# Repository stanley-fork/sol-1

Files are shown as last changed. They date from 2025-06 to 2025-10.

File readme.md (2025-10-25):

# Sol-1 Homebrew Minicomputer

Sol-1 is a homebrew CPU and Minicomputer built from 74HC logic.
It is published here for educational purposes.

### Directory Struture
| Folder Name | Description |
| --- | --- |
| ccompiler | a c compiler written for the Sol-1 CPU. It outputs Sol-1 assembly |
| hardware | schematics, board pictures, microcode assembler |
| software | bios, kernel, shell, and unix utilities programs written in ASM for Sol-1 |
| solarium | the operating system for Sol-1 |
| systemverilog | systemverilog models for the Sol-1 CPU, computer, and a few other things |
| general_docs  | datasheets and miscellaneous documents related to Sol-1 and digital design in general | 
| sol1_docs | documents directly related to Sol-1 | 

## Features
### Hardware
- User and Kernel privilege modes, with up to 256 processes running in parallel.
- Paged virtual memory, such that each process can have a total of 64KB RAM for itself.
- Two serial ports (16550), a real time clock(M48T02), 2 parallel ports(8255), a programmable timer(8253), an IDE hard-drive interface(2.5 Inch HDD), a sound chip(AY-3-8910),
5.25" floppy drive controller (WD1770).
- 8 prioritized external interrupts
- DMA channel
- The sequencer is microcoded, with 15 ROMS operating horizontally
- 8/16-Bit MUL and DIV instructions
- Fast indexed string instructions in the spirit of x86's REP MOVSB, CMPSB, LODSB, STOSB, etc
- 32bit IEEE 754 Floating Point Unit (Under Development)
- 5.25" floppy drive :)

### Register Table
#### General Purpose Registers

| 16bit | 8bit  | Description |
| ----- | ----- | --- |
| A | AH/AL | Accumulator |
| B | BH/BL | Base Register (Secondary Counter Register) |
| C | CH/CL | Counter Register (Primary Counter) |
| D | DH/DL | Data Register / Data Pointer |
| G | GH/GL | General Register (For scratch) |

#### Special Purpose Registers

| 16bit  | 8bit | Description |
| --- | --- | --- |
| PC | | Program Counter |
| SP | | Stack Pointer |
| SSP | | Supervisor Stack Pointer |
| BP | | Base Pointer (Used to manage stack frames) |
| SI | | Source Index (Source address for string operations) |
| DI | | Destination Index (Destination address for string operations) |
| PTB | | Page Table Base |
| Status | | CPU Status |
| Flags  | | Arithmetic and Logic flags register |

### Software
- Unix-like operating system (in progress and very early)
- C compiler that generates a Sol-1 assembly output file
- SystemVerilog model

[Video demonstrations here](https://www.youtube.com/@PauloConstantino167/videos)

Wirewrap Board
Register Board
Front
Boot
Front

### Licensing Terms

Sol-1 Homebrew CPU/Minicomputer is a CPU + system around it, made from 74 series logic from scratch
as an educational project.
Copyright (C) 2025  Paulo Constantino

This program is free software; you can redistribute it and/or
modify it under the terms of the GNU General Public License
as published by the Free Software Foundation; either version 2
of the License, or (at your option) any later version.

This program is distributed in the hope that it will be useful,
but WITHOUT ANY WARRANTY; without even the implied warranty of
MERCHANTABILITY or FITNESS FOR A PARTICULAR PURPOSE.  See the
GNU General Public License for more details.

You should have received a copy of the GNU General Public License
along with this program; if not, see
<https://www.gnu.org/licenses/>.

contact: pconstantino@sol-1.org

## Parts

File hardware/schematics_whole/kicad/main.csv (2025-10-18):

# | Reference | Qty | Value | Footprint | DNP
1 | FLAGS0, IC32, IC33, IC60, IC75, IC76, IC77, IC78, IC79, IC134, IC135, IC136, IC231, IC259, IC266, IC267, IC334, IC336, IC338, INT_STATUS_REG0 | 20 | 74273N | main:DIL20
2 | IC1, IC13, IC15, IC39, IC49, IC55, IC63, IC90, IC98, IC100, IC104, IC112, IC114, IC118, IC121, IC122, IC125, IC127, IC142, IC147, IC195, IC206, IC341 | 23 | 74257N | main:DIL16
3 | IC2, IC3, IC5, IC6, IC9, IC12, IC14, IC16, IC20, IC23, IC30, IC41, IC42, IC44, IC53, IC56, IC61, IC62, IC67, IC68, IC69, IC71, IC80, IC81, IC82, IC84, IC85, IC86, IC87, IC88, IC89, IC130, IC133, IC141, IC144, IC152, IC160 | 37 | 74151N | main:DIL16
4 | IC4, IC17, IC26, IC27, IC65, IC72, IC97, IC120, IC150, IC161, IC163, IC185, IC207, IC209, IC211, IC218, IC219, IC222, IC223, IC224, IC225, IC228, IC229, IC230 | 24 | 74244N | main:DIL20
5 | IC7, IC24, IC54, IC96, IC128, IC129, IC131, IC132 | 8 | 74157N | main:DIL16
6 | IC8, IC19, IC28, IC31, IC48, IC57, IC66, IC99, IC101, IC102, IC106, IC109, IC110, IC117, IC123, IC157, IC158, IC159, IC162, IC165, IC166, IC169, IC171, IC172, IC177, IC178, IC183, IC184, IC198, IC204, IC210, IC245, IC260, INT_CODE_REG1 | 34 | 74377N | main:DIL20
7 | IC10, IC11 | 2 | 74181N | main:DIL24-6
8 | IC18, IC94, IC151, IC153, IC167, IC174, IC263 | 7 | 7432N | main:DIL14
9 | IC21, IC140 | 2 | 58C256P | main:DIL28-6
10 | IC22, IC45, IC93, IC119, IC143, IC146, IC201, IC236 | 8 | 7408N | main:DIL14
11 | IC25, IC173, IC202 | 3 | 7427N | main:DIL14
12 | IC29, IC34, IC35, IC36, IC37, IC38, IC40, IC47, IC64, IC73, IC83, IC92, IC103, IC116, IC124, IC180, IC237, IC241, IC255, IC270 | 20 | 74153N | main:DIL16
13 | IC43, IC115, IC138, IC154, IC155, IC156, IC176, IC196, IC197, IC205, IC_04_2 | 11 | 7404N | main:DIL14
14 | IC46, IC50, IC51, IC52 | 4 | 74283N | main:DIL16
15 | IC58 | 1 | 7411N | main:DIL14
16 | IC59, IC175, IC_86_0, IC_86_1 | 4 | 7486N | main:DIL14
17 | IC74, IC107, IC108, IC126, IC137, IC190 | 6 | 7474N | main:DIL14
18 | IC91, IC95, IC111, IC113, IC170, IC179, IC181, IC182 | 8 | 74253N | main:DIL16
19 | IC105 | 1 | 74148N | main:DIL16
20 | IC139, IC148 | 2 | 7400N | main:DIL14
21 | IC145, IC_10_0 | 2 | 7410N | main:DIL14
22 | IC149, IC164, IC254 | 3 | 74138N | main:DIL16
23 | IC168 | 1 | 7420N | main:DIL14
24 | IC186 | 1 | 4040N | main:DIL16
25 | IC187 | 1 | 431000 | main:DIL32
26 | IC188, IC199, IC227, IC243, IC257, IC258, IC261, IC262, IC264, IC265, IC302, IC303, IC333, IC335, IC337, IC339 | 16 | 27512 | main:DIL28
27 | IC192, IC193, IC194, IC411 | 4 | 74279N | main:DIL16
28 | IC203 | 1 | 7430N | main:DIL14
29 | IC208 | 1 | 74245N | main:DIL20
30 | IC412 | 1 | 74173N | main:DIL16
31 | IC_02_0 | 1 | 7402N | main:DIL14
32 | R1, R2, R3, R4, R5, R6, R7, R8, R9, R10, R11, R12, R13, R14, R15, R16, R17, R18, R19, R20, R21, R22, R23, R24, R25, R26, R27, R28 | 28 | R-US_0204/2V | main:0204V
33 | S5, S7, S8 | 3 | tl36po | main:TL3XPO
34 | SW1, SW2, SW3, SW4, SW5 | 5 | SW_DIP-8 | main:EDG-08
35 | U1, U2, U3, U4, U5, U6, U7, U8 | 8 | as6c4008-55pcn | main:DIP254P1524X393-32

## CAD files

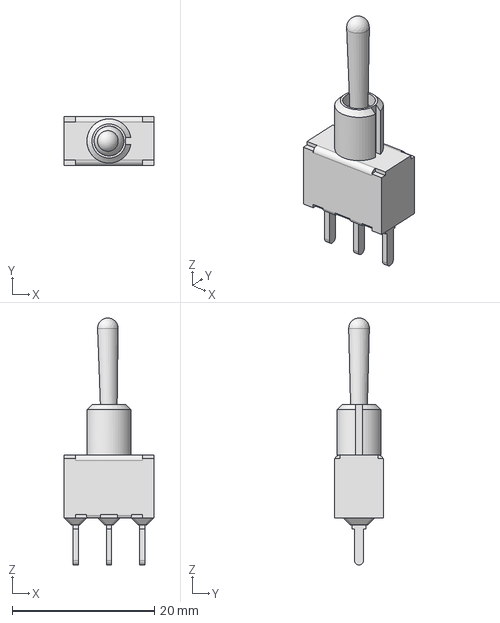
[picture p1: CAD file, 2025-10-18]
hardware/schematics_whole/kicad_models/100SP1T1B4M2QE.step
12.7 x 6.86 x 34.8 mm

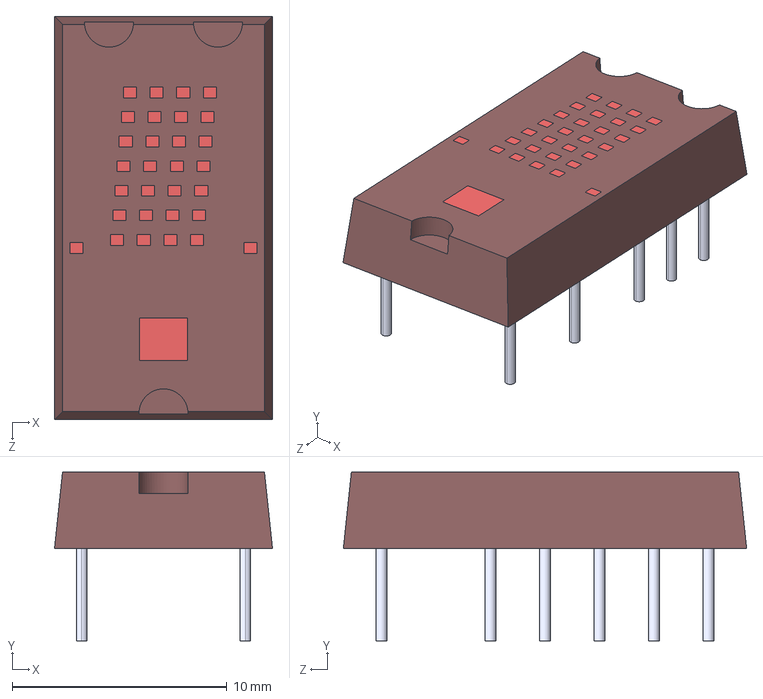
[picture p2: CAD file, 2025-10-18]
hardware/schematics_whole/kicad_models/KiCad-libs-master/TIL311--3DModel-STEP-56544.STEP
10.2 x 7.87 x 18.8 mm

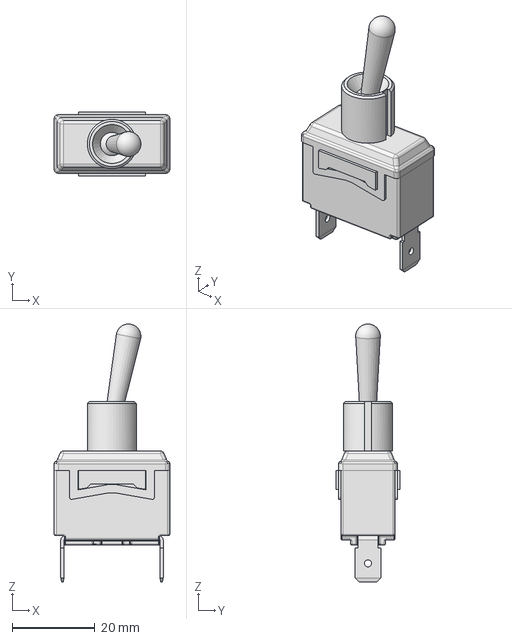
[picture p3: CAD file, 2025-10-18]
hardware/schematics_whole/kicad_models/ST141D00.step
28.0 x 15.5 x 62.4 mm

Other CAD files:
hardware/photon/main.obj
hardware/photon/photon.obj

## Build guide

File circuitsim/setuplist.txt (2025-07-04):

### setuplist.txt first line must be a comment
+Basics
ohms.txt Ohm's Law
resistors.txt Resistors
cap.txt Capacitor
induct.txt Inductor
>lrc.txt LRC Circuit
voltdivide.txt Voltage Divider
pot.txt Potentiometer
potdivide.txt Potentiometer Divider
thevenin.txt Thevenin's Theorem
norton.txt Norton's Theorem
-
+A/C Circuits
capac.txt Capacitor
inductac.txt Inductor
capmultcaps.txt Caps of Various Capacitances
capmultfreq.txt Caps w/ Various Frequencies
indmultind.txt Inductors of Various Inductances
indmultfreq.txt Inductors w/ Various Frequencies
impedance.txt Impedances of Same Magnitude
res-series.txt Series Resonance
res-par.txt Parallel Resonance
-
+Passive Filters
filt-hipass.txt High-Pass Filter (RC)
filt-lopass.txt Low-Pass Filter (RC)
filt-hipass-l.txt High-Pass Filter (RL)
filt-lopass-l.txt Low-Pass Filter (RL)
bandpass.txt Band-pass Filter
notch.txt Notch Filter
twint.txt Twin-T Filter
crossover.txt Crossover
butter10lo.txt Butterworth Low-Pass (10 pole)
besselbutter.txt Bessel vs Butterworth
ringing.txt Band-pass with Ringing
-
+Other Passive Circuits
+Series/Parallel
indseries.txt Inductors in Series
indpar.txt Inductors in Parallel
capseries.txt Caps in Series
cappar.txt Caps in Parallel
-
+Transformers
transformer.txt Transformer
transformerdc.txt Transformer w/ DC
transformerup.txt Step-Up Transformer
transformerdown.txt Step-Down Transformer
longdist.txt Long-Distance Power Transmission
-
+Relays
relay.txt Relay
relayand.txt Relay AND
relayor.txt Relay OR
relayxor.txt Relay XOR
relaymux.txt Relay Mux
relayff.txt Relay Flip-Flop
relaytff.txt Relay Toggle Flip-Flop
relayctr.txt Relay Counter
-
3way.txt 3-Way Light Switches
4way.txt 3- and 4-Way Light Switches
diff.txt Differentiator
wheatstone.txt Wheatstone Bridge
lrc-critical.txt Critically Damped LRC
currentsrcelm.txt Current Source
inductkick.txt Inductive Kickback
inductkick-snub.txt Blocking Inductive Kickback
powerfactor1.txt Power Factor
powerfactor2.txt Power Factor Correction
grid.txt Resistor Grid
grid2.txt Resistor Grid 2
cube.txt Resistor Cube
+Coupled LC's
coupled1.txt LC Modes (2)
coupled2.txt Weak Coupling
coupled3.txt LC Modes (3)
ladder.txt LC Ladder
-
phaseseq.txt Phase-Sequence Network
lissa.txt Lissajous Figures
-
+Diodes
diodevar.txt Diode
diodecurve.txt Diode I/V Curve
rectify.txt Half-Wave Rectifier
fullrect.txt Full-Wave Rectifier
fullrectf.txt Full-Wave Rectifier w/ Filter
diodelimit.txt Diode Limiter
+Zener Diodes
zeneriv.txt I/V Curve
zenerref.txt Voltage Reference
zenerreffollow.txt Voltage Reference w/ Follower
-
dcrestoration.txt DC Restoration
inductkick-block.txt Blocking Inductive Kickback
spikegen.txt Spike Generator
+Voltage Multipliers
voltdouble.txt Voltage Doubler
voltdouble2.txt Voltage Doubler 2
volttriple.txt Voltage Tripler
voltquad.txt Voltage Quadrupler
-
amdetect.txt AM Detector
diodeclip.txt Waveform Clipper
sinediode.txt Triangle-to-Sine Converter
ringmod.txt Ring Modulator
-
+Op-Amps
opamp.txt Op-Amp
opampfeedback.txt Op-Amp Feedback
+Amplifiers
amp-invert.txt Inverting Amplifier
amp-noninvert.txt Noninverting Amplifier
amp-follower.txt Follower
amp-diff.txt Differential Amplifier
amp-sum.txt Summing Amplifier
logconvert.txt Log Amplifier
classd.txt Class-D Amplifier
-
+Oscillators
relaxosc.txt Relaxation Oscillator
phaseshiftosc.txt Phase-Shift Oscillator
triangle.txt Triangle Wave Generator
sine.txt Sine Wave Generator
sawtooth.txt Sawtooth Wave Generator
vco.txt Voltage-Controlled Oscillator
rossler.txt Rossler Circuit
-
amp-rect.txt Half-Wave Rectifier (inverting)
amp-fullrect.txt Full-Wave Rectifier
peak-detect.txt Peak Detector
amp-integ.txt Integrator
amp-dfdx.txt Differentiator
amp-schmitt.txt Schmitt Trigger
nic-r.txt Negative Impedance Converter
gyrator.txt Gyrator
capmult.txt Capacitance Multiplier
howland.txt Howland Current Source
itov.txt I-to-V Converter
opamp-regulator.txt Voltage Regulator
opint.txt 741 Internals
opint-invert-amp.txt 741 (inverting amplifier)
opint-slew.txt 741 Slew Rate
opint-current.txt 741 Current Limits
-
+Transistors
npn.txt NPN Transistor
pnp.txt PNP Transistor
transswitch.txt Switch
follower.txt Emitter Follower
+Multivibrators
multivib-a.txt Astable Multivib
multivib-bi.txt Bistable Multivib (Flip-Flop)
multivib-mono.txt Monostable Multivib (One-Shot)
-
ceamp.txt Common-Emitter Amplifier
phasesplit.txt Unity-Gain Phase Splitter
schmitt.txt Schmitt Trigger
currentsrc.txt Current Source
currentsrcramp.txt Current Source Ramp
mirror.txt Current Mirror
darlington.txt Darlington Pair
+Differential Amplifiers
trans-diffamp.txt Differential Input
trans-diffamp-common.txt Common-Mode Input
trans-diffamp-cursrc.txt Common-Mode w/Current Source
-
+Push-Pull Follower
pushpullxover.txt Simple, with distortion
pushpull.txt Improved
-
+Oscillators
colpitts.txt Colpitts Oscillator
hartley.txt Hartley Oscillator
eclosc.txt Emitter-Coupled LC Oscillator
-
-
+MOSFETs
nmosfet.txt n-MOSFET
pmosfet.txt p-MOSFET
mosswitch.txt Switch
mosfollower.txt Source Follower
moscurrentsrc.txt Current Source
moscurrentramp.txt Current Ramp
mosmirror.txt Current Mirror
mosfetamp.txt Common-Source Amplifier
cmosinverter.txt CMOS Inverter
cmosinvertercap.txt CMOS Inverter (w/capacitance)
cmosinverterslow.txt CMOS Inverter (slow transition)
cmostransgate.txt CMOS Transmission Gate
mux.txt CMOS Multiplexer
samplenhold.txt Sample-and-Hold
delayrc.txt Delayed Buffer
leadingedge.txt Leading-Edge Detector
switchfilter.txt Switchable Filter
voltinvert.txt Voltage Inverter
invertamp.txt Inverter Amplifier
inv-osc.txt Inverter Oscillator
-
+555 Timer Chip
555square.txt Square Wave Generator
555int.txt Internals
555saw.txt Sawtooth Oscillator
555lowduty.txt Low-duty-cycle Oscillator
555monostable.txt Monostable Multivibrator
555pulsemod.txt Pulse Width Modulator
555sequencer.txt Pulse Sequencer
555schmitt.txt Schmitt Trigger (inverting)
555missing.txt Missing Pulse Detector
-
+Active Filters
filt-vcvs-lopass.txt VCVS Low-Pass Filter
filt-vcvs-hipass.txt VCVS High-Pass Filter
switchedcap.txt Switched-Capacitor Filter
allpass1.txt Allpass
allpass2.txt Allpass w/ Square
-
+Logic Families
+RTL
rtlinverter.txt RTL Inverter
rtlnor.txt RTL NOR
rtlnand.txt RTL NAND
-
+DTL
dtlinverter.txt DTL Inverter
dtlnand.txt DTL NAND
dtlnor.txt DTL NOR
-
+TTL
ttlinverter.txt TTL Inverter
ttlnand.txt TTL NAND
ttlnor.txt TTL NOR
-
+NMOS
nmosinverter.txt NMOS Inverter
nmosinverter2.txt NMOS Inverter 2
nmosnand.txt NMOS NAND
-
+CMOS
cmosinverter.txt CMOS Inverter
cmosnand.txt CMOS NAND
cmosnor.txt CMOS NOR
cmosxor.txt CMOS XOR
cmosff.txt CMOS Flip-Flop
cmosmsff.txt CMOS Master-Slave Flip-Flop
-
+ECL
eclnor.txt ECL NOR/OR
-
+Ternary
3-cgand.txt CGAND
3-cgor.txt CGOR
3-invert.txt Complement (F210)
3-f211.txt F211
3-f220.txt F220
3-f221.txt F221
-
-
+Combinational Logic
xor.txt Exclusive OR
halfadd.txt Half Adder
fulladd.txt Full Adder
decoder.txt 1-of-4 Decoder
mux3state.txt 2-to-1 Mux
majority.txt Majority Logic
digcompare.txt 2-Bit Comparator
7segdecoder.txt 7-Segment LED Decoder
-
+Sequential Logic
+Flip-Flops
nandff.txt SR Flip-Flop
clockedsrff.txt Clocked SR Flip-Flop
masterslaveff.txt Master-Slave Flip-Flop
edgedff.txt Edge-Triggered D Flip-Flop
jkff.txt JK Flip-Flop
-
+Counters
counter.txt 4-Bit Ripple Counter
counter8.txt 8-Bit Ripple Counter
synccounter.txt Synchronous Counter
deccounter.txt Decimal Counter
graycode.txt Gray Code Counter
johnsonctr.txt Johnson Counter
-
divideby2.txt Divide-by-2
divideby3.txt Divide-by-3
ledflasher.txt LED Flasher
traffic.txt Traffic Light
dram.txt Dynamic RAM
-
+Analog/Digital
flashadc.txt Flash ADC
deltasigma.txt Delta-Sigma ADC
hfadc.txt Half-Flash (Subranging) ADC
dac.txt Binary-Weighted DAC
r2rladder.txt R-2R Ladder DAC
swtreedac.txt Switch-Tree DAC
digsine.txt Digital Sine Wave
-
+Phase-Locked Loops
xorphasedet.txt XOR Phase Detector
pll.txt Type I PLL
phasecomp.txt Phase Comparator (Type II)
phasecompint.txt Phase Comparator Internals
pll2.txt Type II PLL
pll2a.txt Type II PLL (fast)
freqdouble.txt Frequency Doubler
-
+Transmission Lines
tl.txt Simple TL
tlstand.txt Standing Wave
tlterm.txt Termination
tlmismatch.txt Mismatched lines (Pulse)
tlmis1.txt Mismatched lines (Standing Wave)
tlmatch1.txt Impedance Matching (L-Section)
tlmatch2.txt Impedance Matching (Shunt Stub)
tlfreq.txt Stub Frequency Response
tllopass.txt Low-Pass Filter
tllight.txt Light Switch
-
+Misc Devices
+JFETs
jfetcurrentsrc.txt JFET Current Source
jfetfollower.txt JFET Follower
jfetfollower-nooff.txt JFET Follower w/zero offset
jfetamp.txt Common-Source Amplifier
volume.txt Volume Control
-
+Tunnel Diodes
tdiode.txt I/V Curve
tdosc.txt LC Oscillator
tdrelax.txt Relaxation Oscillator
-
+Memristors
mr.txt Memristor
mr-sine.txt Sine Wave
mr-square.txt Square Wave
mr-triangle.txt Triangle Wave
mr-sine2.txt Hard-Switching 1
mr-sine3.txt Hard-Switching 2
mr-crossbar.txt Crossbar Memory
-
+Triodes
triode.txt Triode
triodeamp.txt Amplifier
-
+Silicon-Controlled Rectifiers
scr.txt SCR
scractrig.txt AC Trigger
-
+Current Conveyor
cc2.txt CCII+
cc2n.txt CCII-
ccinductor.txt Inductor Simulator
cc2imp.txt CCII+ Implementation
cc2impn.txt CCII- Implementation
cciamp.txt Current Amplifier
ccvccs.txt VCCS
ccdiff.txt Current Differentiator
ccint.txt Current Integrator
ccitov.txt Current-Controlled Voltage Source
-
+Spark Gap
spark-sawtooth.txt Sawtooth Generator
tesla.txt Tesla Coil
spark-marx.txt Marx Generator
-
-
blank.txt Blank Circuit

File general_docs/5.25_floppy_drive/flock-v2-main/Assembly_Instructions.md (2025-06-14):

# Flock Version 2.0 - Assembly Instructions

## Prerequisites

### Tools, Equipment, and Supplies

* Soldering iron with a fine tip. Temperature controlled soldering station is recommended
* Needle nose pliers for forming components' leads
* Small side cutters for cutting components' leads
* Multimeter with frequency measurement, an oscilloscope, or a logic analyzer can be beneficial for troubleshooting
* Desk lamp, magnifying glass
* Solder suitable for soldering electronics. For example: rosin core Sn63/Pb37, Sn60/Pb40, or a lead-free solder such as Sn96.5/Ag3.0/Cu0.5 (sometimes referred to as SAC305)
* Solder wick for removing excess of solder
* 99% Isopropyl Alcohol for removing the excess of flux after soldering
* Lint free wipes, used toothbrush, cotton swabs for cleaning the PCB before and after soldering

### Parts

The table below shows the images of the components included in the kit. The up to date list of parts provided in the [Bill of Materials](README.md#bill-of-materials) section of the [README.md](README.md) file. It also provides the recommended sources for the parts.

Image                                                                                           | Reference | Description                                            | Quantity
----------------------------------------------------------------------------------------------- | --------- | ------------------------------------------------------ | --------
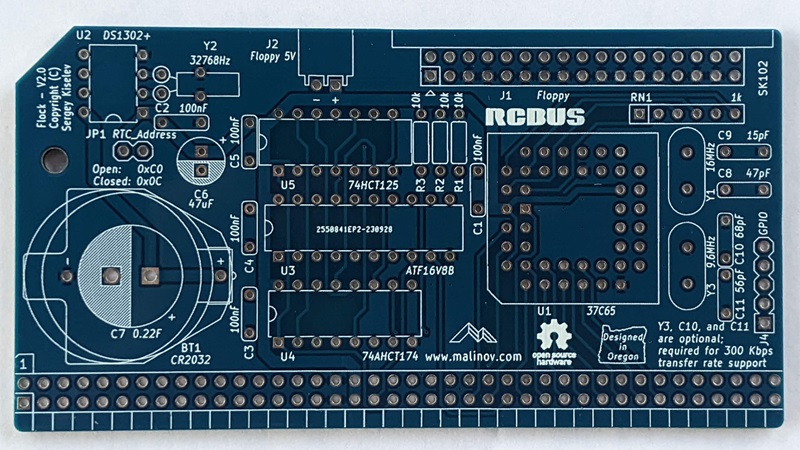
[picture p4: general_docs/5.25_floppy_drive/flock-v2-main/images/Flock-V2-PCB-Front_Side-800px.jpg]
PCB - Flock V2
             | PCB       | Flock PCB - Version 2.0                                | 1
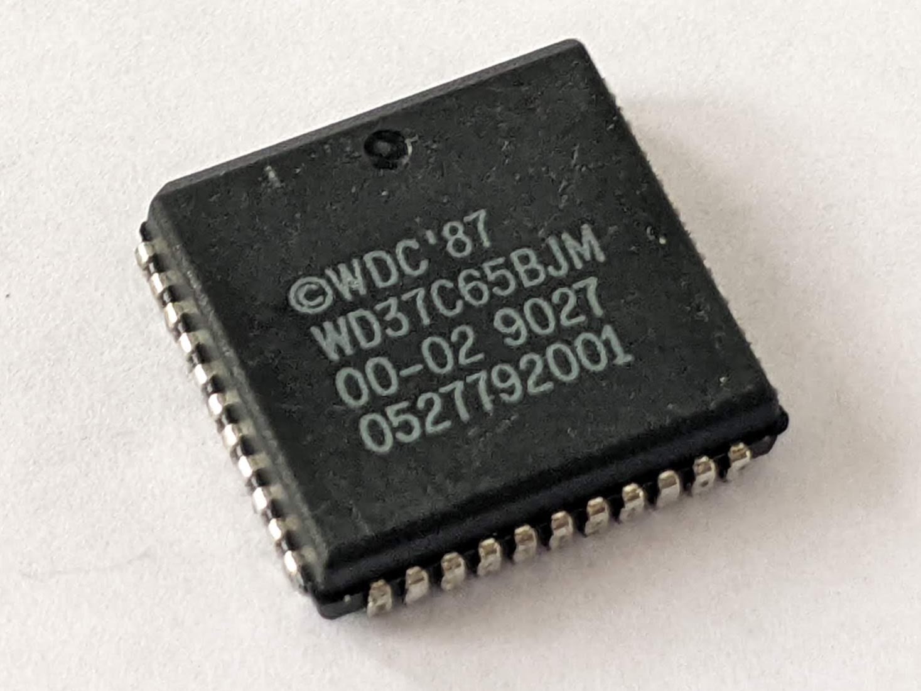
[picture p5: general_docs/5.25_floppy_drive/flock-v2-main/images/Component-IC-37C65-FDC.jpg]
FDC - 37C65
                    | U1        | WD37C65BJM - FDC, CMOS, 44 pin PLCC                    | 1
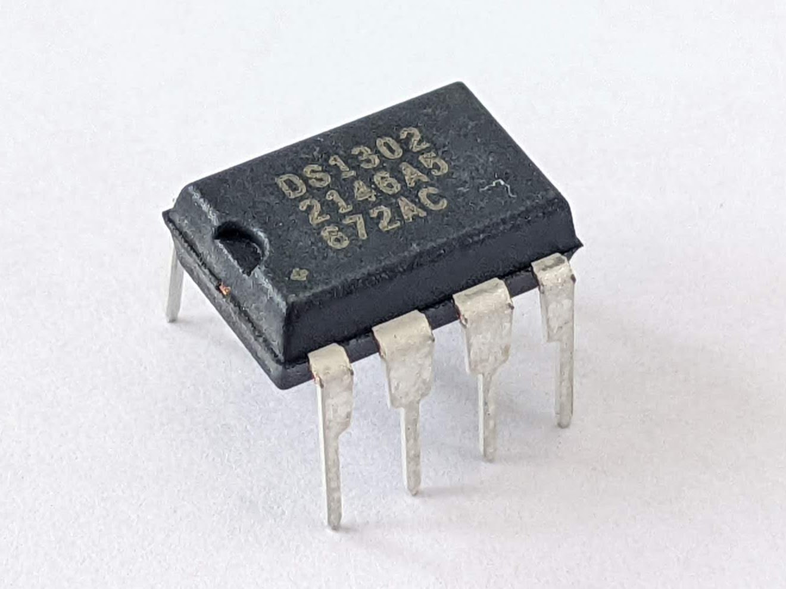
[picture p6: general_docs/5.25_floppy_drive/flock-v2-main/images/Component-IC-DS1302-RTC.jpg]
RTC - DS1302+
                 | U2        | DS1302+ - RTC, 8 pin DIP                               | 1
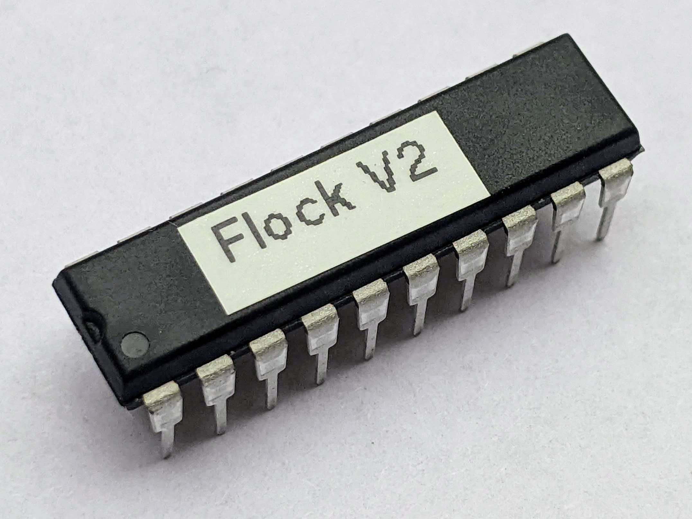
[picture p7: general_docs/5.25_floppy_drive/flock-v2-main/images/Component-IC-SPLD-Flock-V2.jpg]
Flock V2 SPLD - ATF16V8B
   | U3        | ATF16V8B SPLD, programmed with Flock V2 fuse map, 20 pin DIP | 1
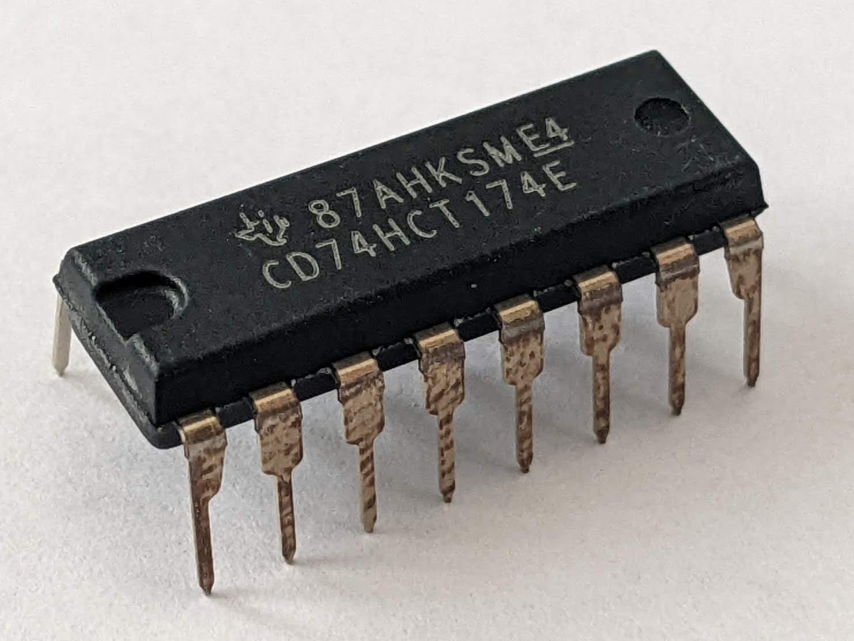
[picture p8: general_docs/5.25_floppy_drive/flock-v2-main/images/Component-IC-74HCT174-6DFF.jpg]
Hex D Flip-Flop - 74HCT174
 | U4        | 74HCT174 - Hex D-type flip-flop with reset, 16 pin DIP | 1
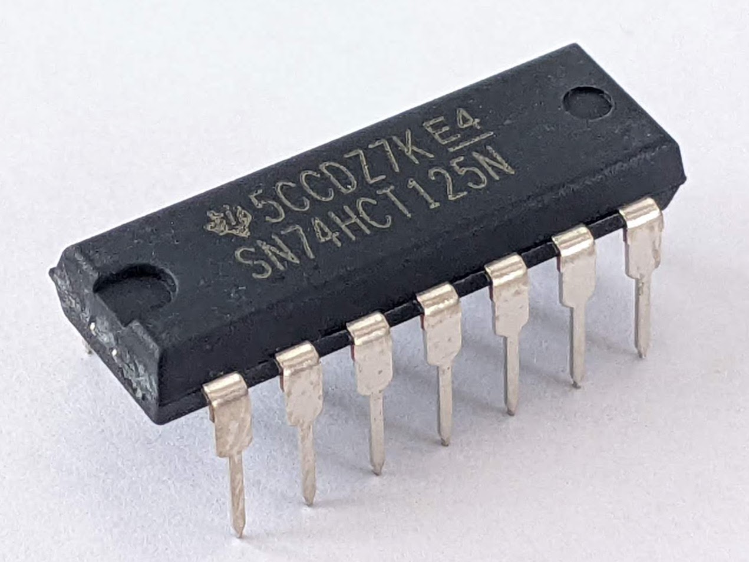
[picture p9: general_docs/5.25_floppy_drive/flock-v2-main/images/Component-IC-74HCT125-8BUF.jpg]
3-State Buffer - 74HCT125
  | U5        | 74HCT125 - Quadruple bus buffer gates with 3-state outputs, 14 pin DIP | 1 
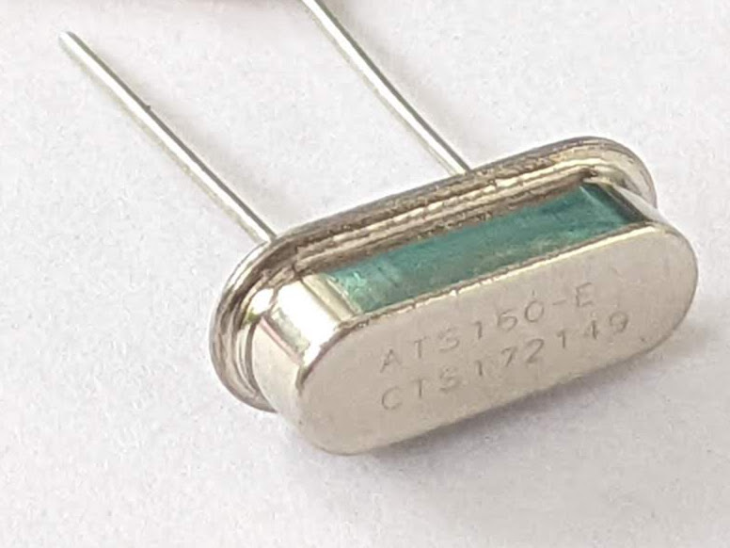
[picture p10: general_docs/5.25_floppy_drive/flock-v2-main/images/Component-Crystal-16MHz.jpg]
16 MHz Quartz Crystal
         | Y1        | Quarts crystal, 16 MHz, series                         | 1
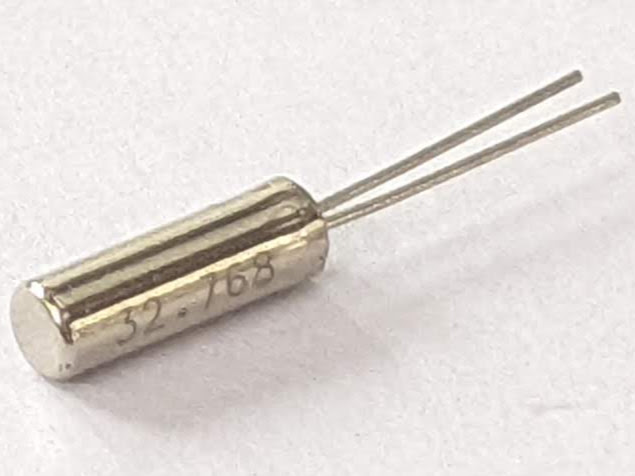
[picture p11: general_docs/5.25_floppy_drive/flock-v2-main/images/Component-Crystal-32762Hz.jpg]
32762 Hz Quartz Crystal
     | Y2        | Quarts crystal, 32768 Hz, 6 pF                         | 1
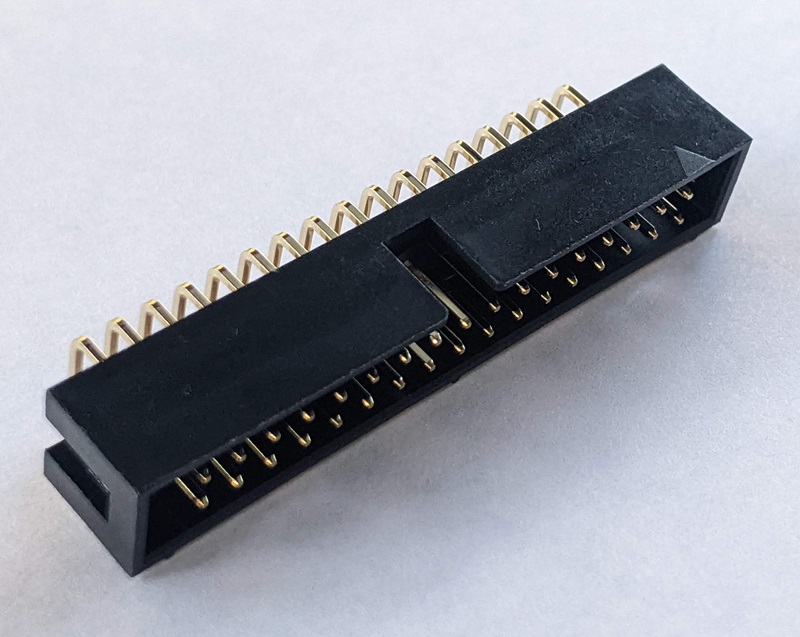
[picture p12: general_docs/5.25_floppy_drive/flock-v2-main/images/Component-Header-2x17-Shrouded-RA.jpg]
2x17 Shrouded Pin Header Right Angle
 | J1      | Pin header, shrouded, 2x17 pins, right angle, 2.54 mm pitch | 1
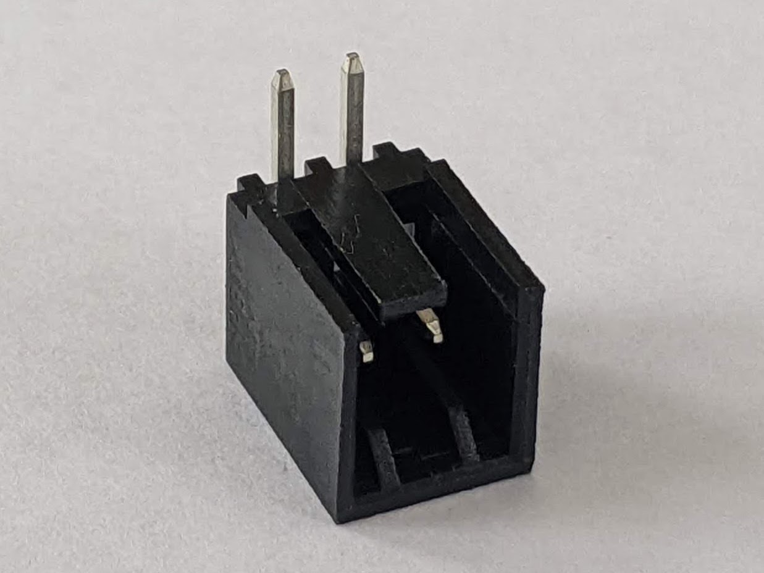
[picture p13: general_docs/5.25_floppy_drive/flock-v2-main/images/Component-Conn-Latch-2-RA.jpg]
Friction Lock Connector
     | J2        | Pin header with friction lock, 2 pins, right angle     | 1 (optional)
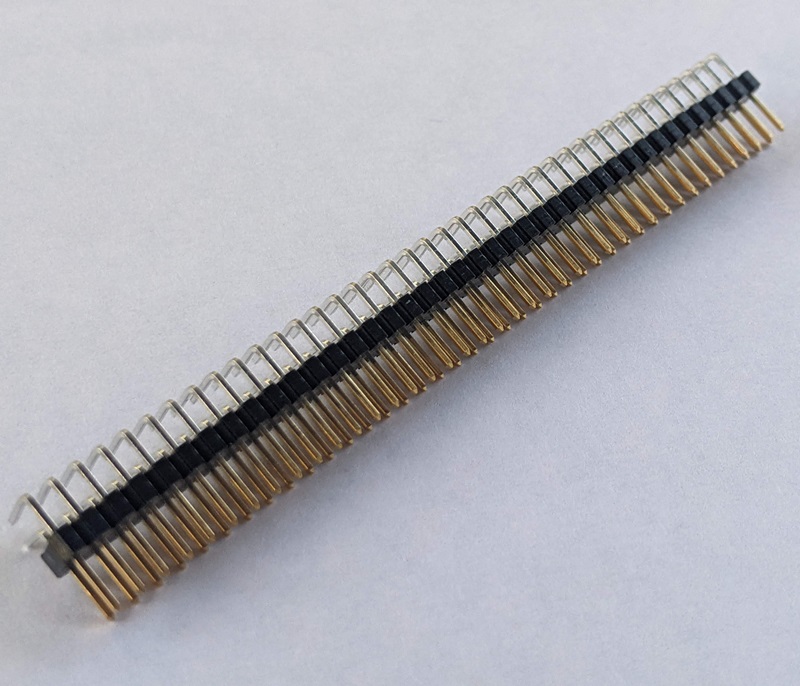
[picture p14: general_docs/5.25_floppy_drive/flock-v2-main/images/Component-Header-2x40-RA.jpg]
Pin Header 2x40 Right Angle
  | J3        | Pin header, 2x40 pins, 2.54 mm pitch, right angle      | 1
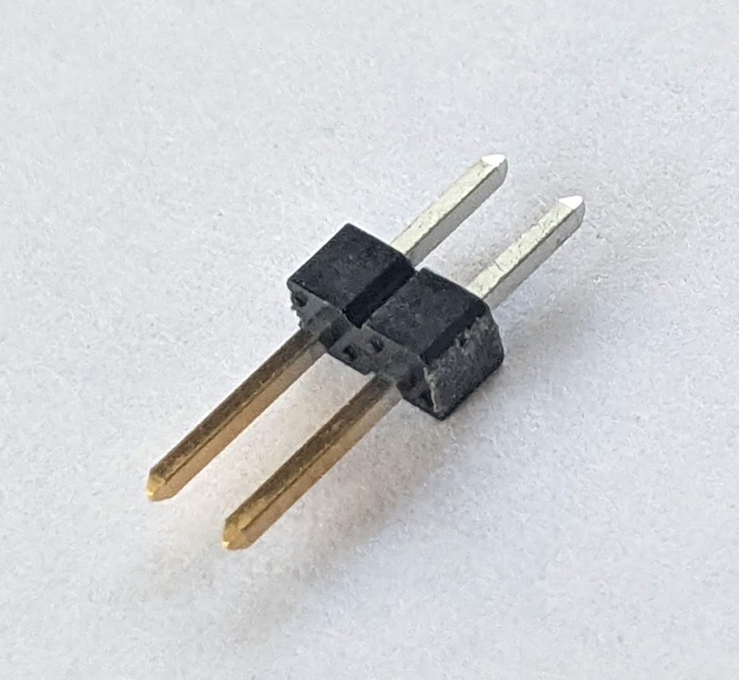
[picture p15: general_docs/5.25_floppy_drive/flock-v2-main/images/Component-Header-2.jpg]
Pin Header 2 pins
                  | JP1       | Pin header, 2 pins, 2.54 mm pitch                      | 1
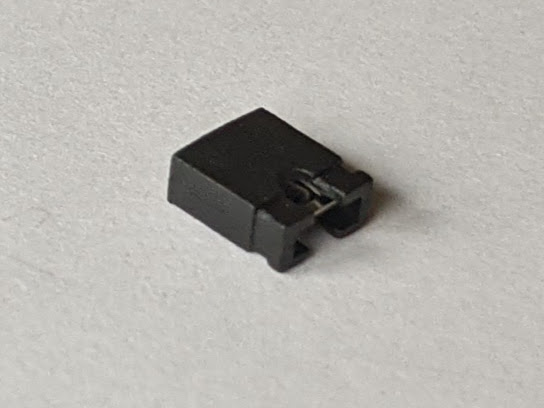
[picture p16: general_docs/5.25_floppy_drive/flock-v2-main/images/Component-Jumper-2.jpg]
Jumper
                             | JP1       | Jumper/Shunt, 2 pin 2.54 mm pitch
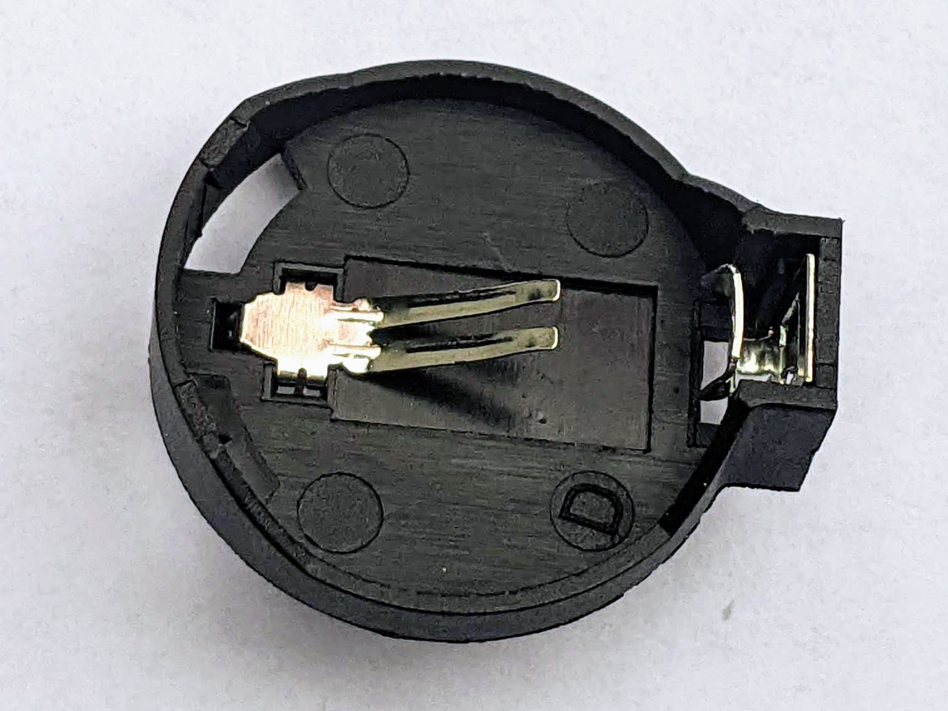
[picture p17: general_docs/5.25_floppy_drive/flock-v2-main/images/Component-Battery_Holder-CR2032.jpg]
CR2032 Battery Holder
 | BT1       | Battery Holder, CR2032 (optional; C7 can be installed instead) | 1
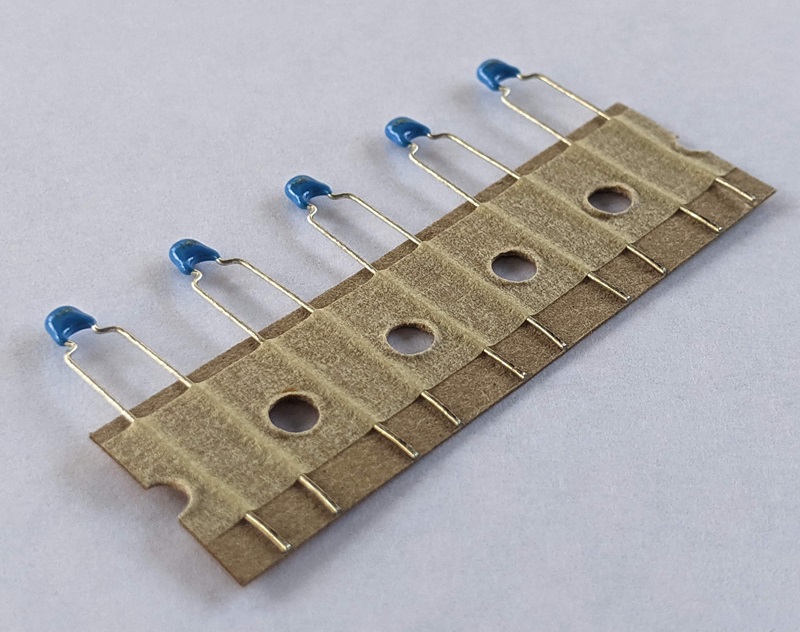
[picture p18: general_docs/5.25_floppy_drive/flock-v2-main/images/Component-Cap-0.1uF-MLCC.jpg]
Ceramic Capacitors - 0.1uF
   | C1 - C5   | Capacitor, MLCC, 0.1 uF, 50V, 5 mm pitch               | 5
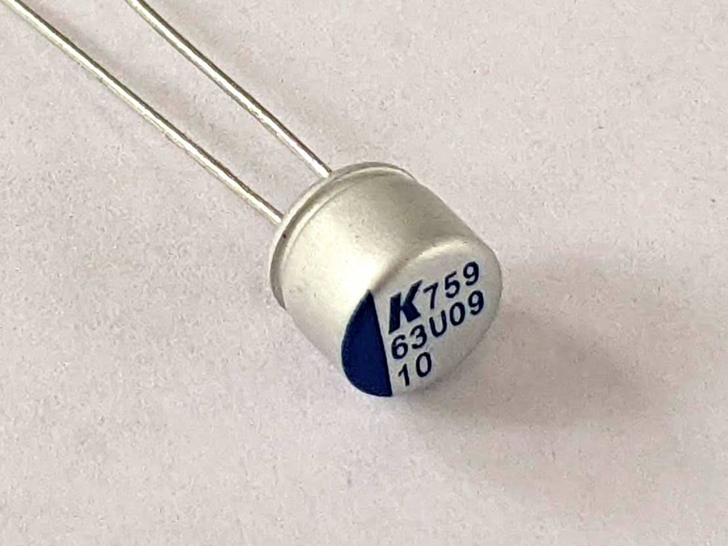
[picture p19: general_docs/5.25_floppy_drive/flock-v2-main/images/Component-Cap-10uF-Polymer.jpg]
Organic Polymer Capacitor - 10uF
 | C6  | Capacitor, Organic Polymer, 10 uF, 63V, 6.3 mm diameter, 2.5 mm pitch (optional; BT1 can be installed instead) | 1
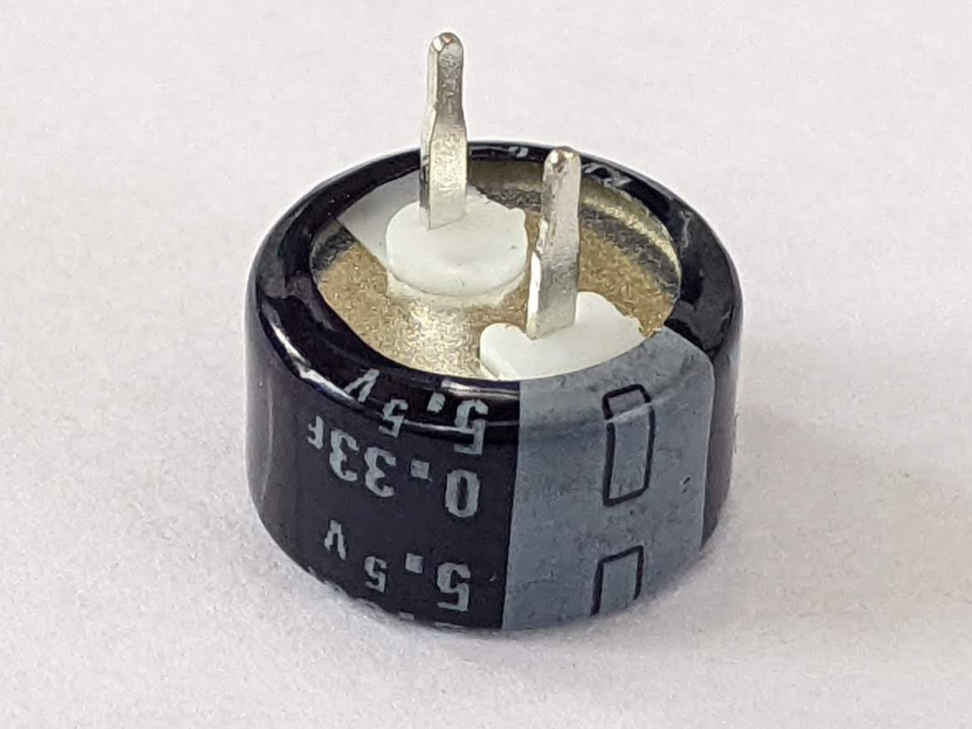
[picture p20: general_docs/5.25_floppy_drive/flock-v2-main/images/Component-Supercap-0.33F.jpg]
Supercapacitor - 0.33F
       | C7        | Supercapacitor, 0.22 F, 5.5V, 13.5 mm diameter, 5 mm pitch            | 1
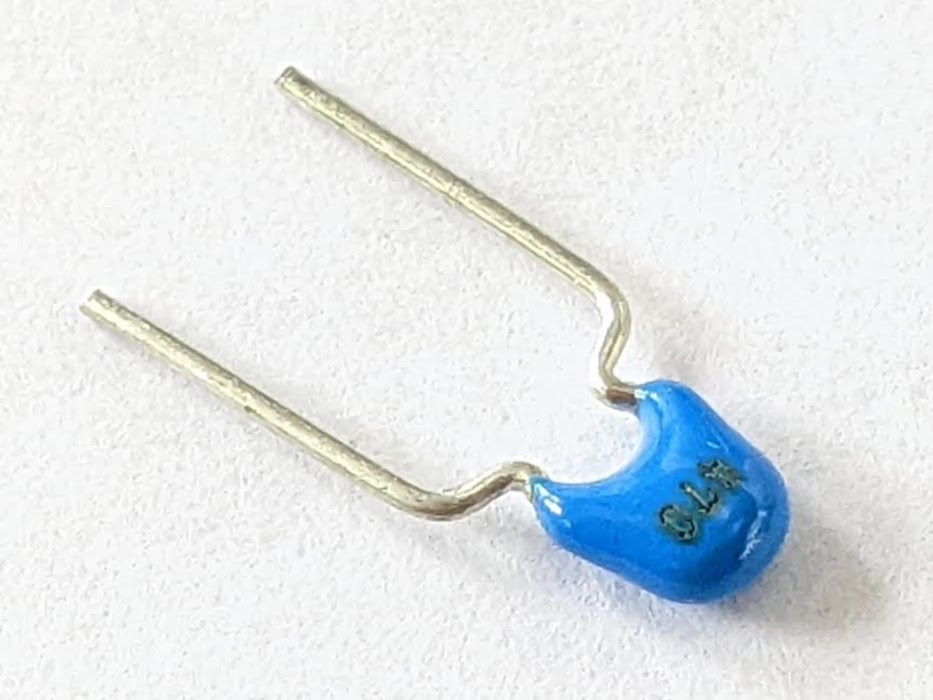
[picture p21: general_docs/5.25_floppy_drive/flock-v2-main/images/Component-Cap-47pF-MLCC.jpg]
Ceramic Capacitor - 47pF
      | C8        | Capacitor, MLCC, 47 pF, 50V, 5 mm pitch                | 1
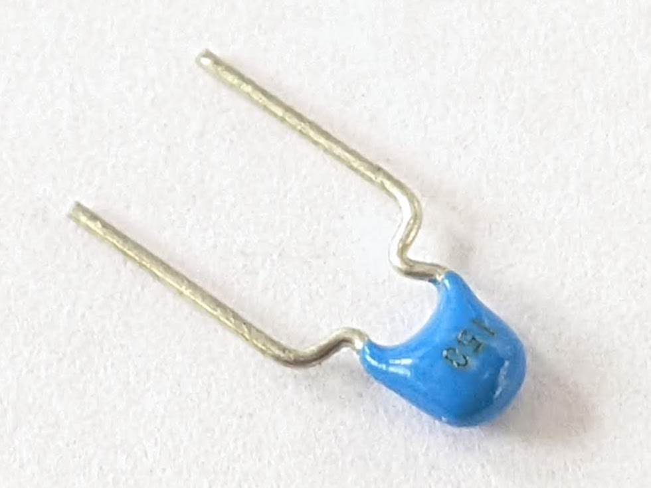
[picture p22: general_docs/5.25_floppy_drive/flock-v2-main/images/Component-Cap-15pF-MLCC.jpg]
Ceramic Capacitor - 15pF
      | C9        | Capacitor, MLCC, 15 pF, 50V, 5 mm pitch                | 1
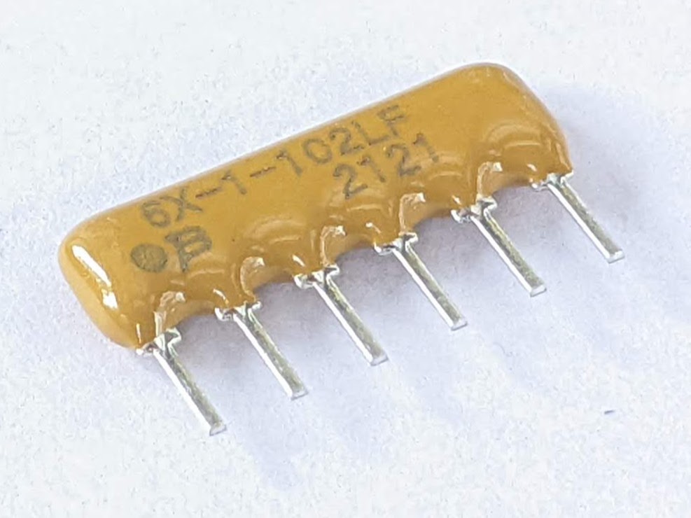
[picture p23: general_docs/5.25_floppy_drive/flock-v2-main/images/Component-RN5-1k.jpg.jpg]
Resistor Network - 5x1k
          | RN1       | Resistor Network, 1 kohm, bussed, 6 pin SIP            | 1
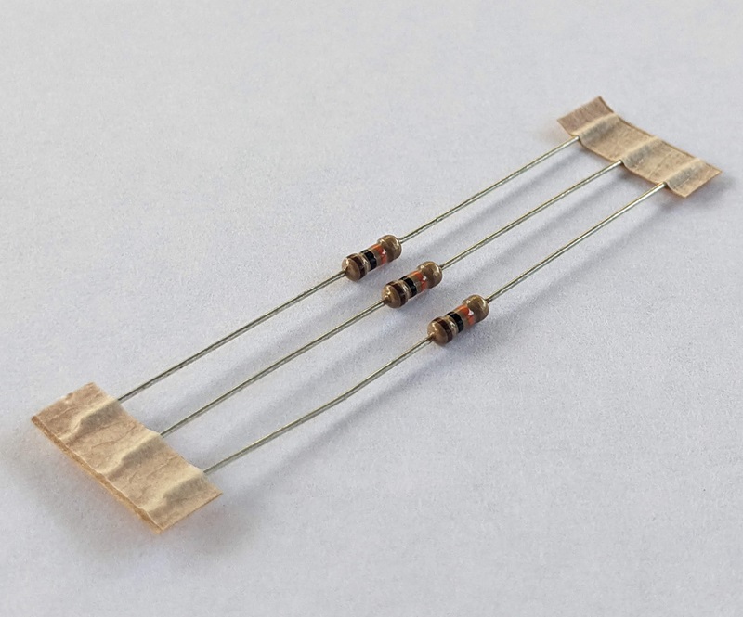
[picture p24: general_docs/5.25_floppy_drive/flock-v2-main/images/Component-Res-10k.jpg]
Resistors - 10k
                    | R1 - R3    | Resistor, 10 kohm, 0.25 W, axial                       | 2
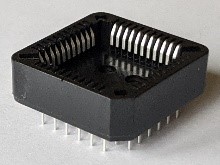
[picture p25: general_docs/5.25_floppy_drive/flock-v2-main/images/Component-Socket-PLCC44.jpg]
IC Socket - PLCC44
            | U1        | Integrated circuit socket, 44 pin PLCC, through hole   | 1
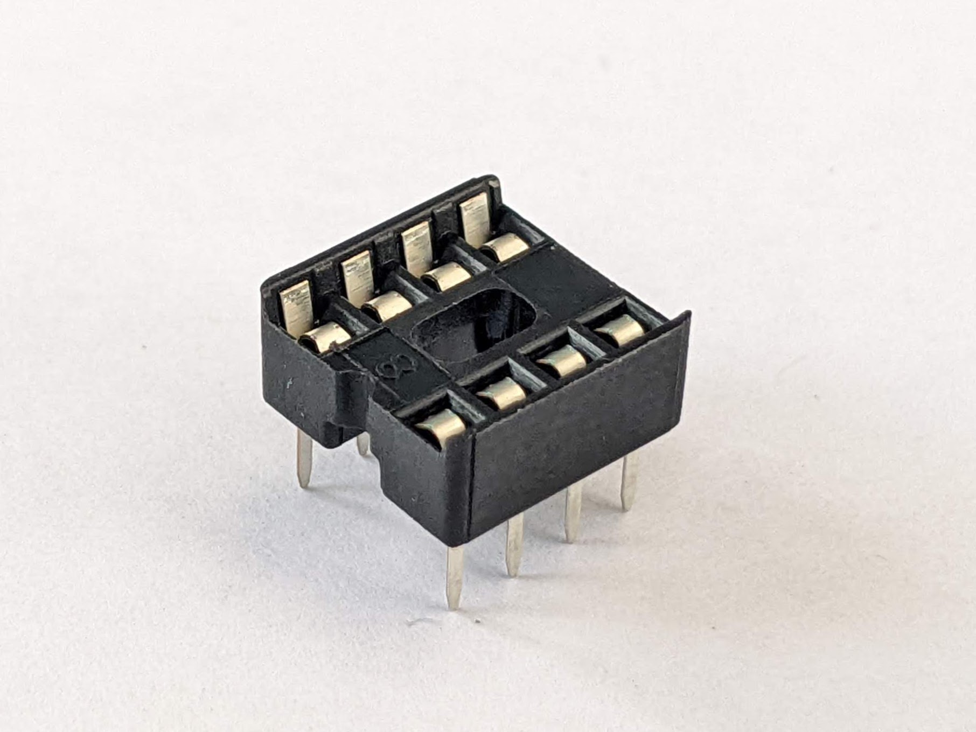
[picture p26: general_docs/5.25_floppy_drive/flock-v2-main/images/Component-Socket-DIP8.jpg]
IC Socket - DIP8
                | U2        | Integrated circuit socket, 8 pin DIP                   | 1 (optional)
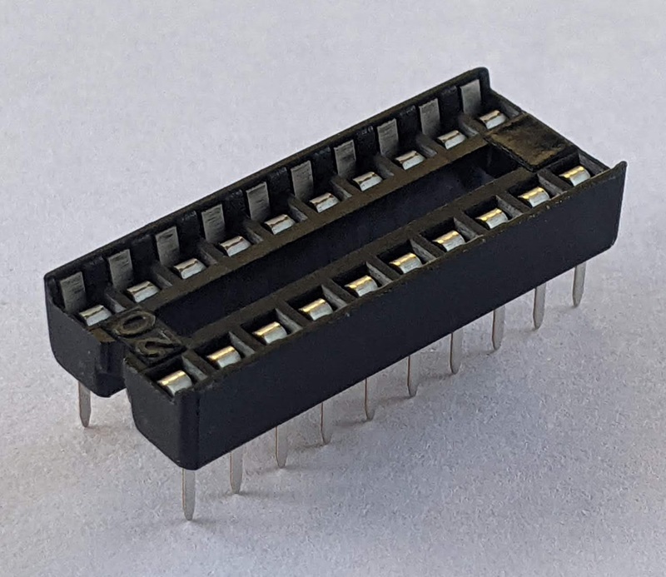
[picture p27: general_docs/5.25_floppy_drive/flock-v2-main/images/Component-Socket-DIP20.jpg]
IC Socket - DIP20
              | U3        | Integrated circuit socket, 20 pin DIP                  | 1 (optional)
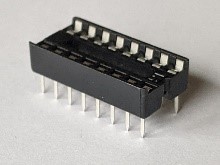
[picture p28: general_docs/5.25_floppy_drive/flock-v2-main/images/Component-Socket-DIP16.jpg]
IC Socket - DIP16
              | U4        | Integrated circuit socket, 16 pin DIP                  | 1 (optional)
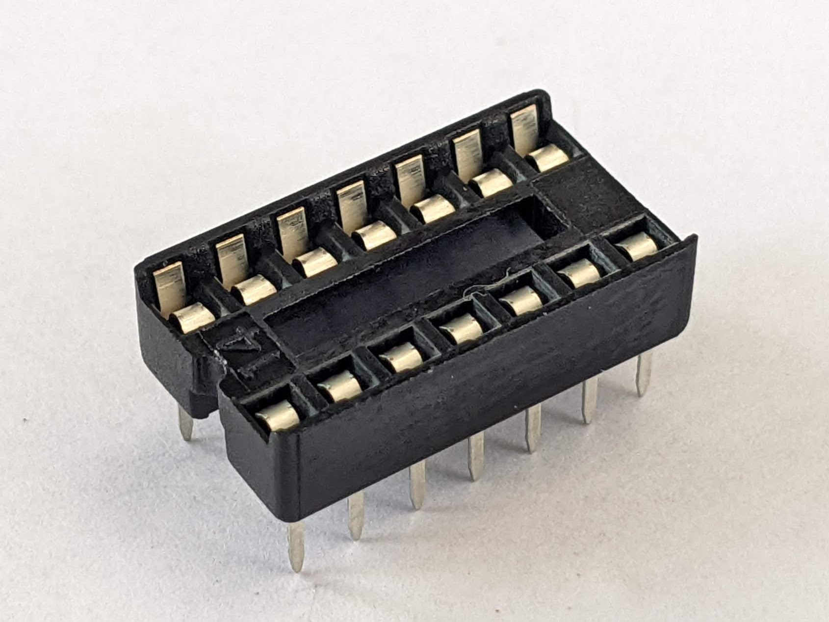
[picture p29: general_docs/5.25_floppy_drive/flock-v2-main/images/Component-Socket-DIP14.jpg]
IC Socket - DIP16
              | U5        | Integrated circuit socket, 14 pin DIP                  | 1 (optional)
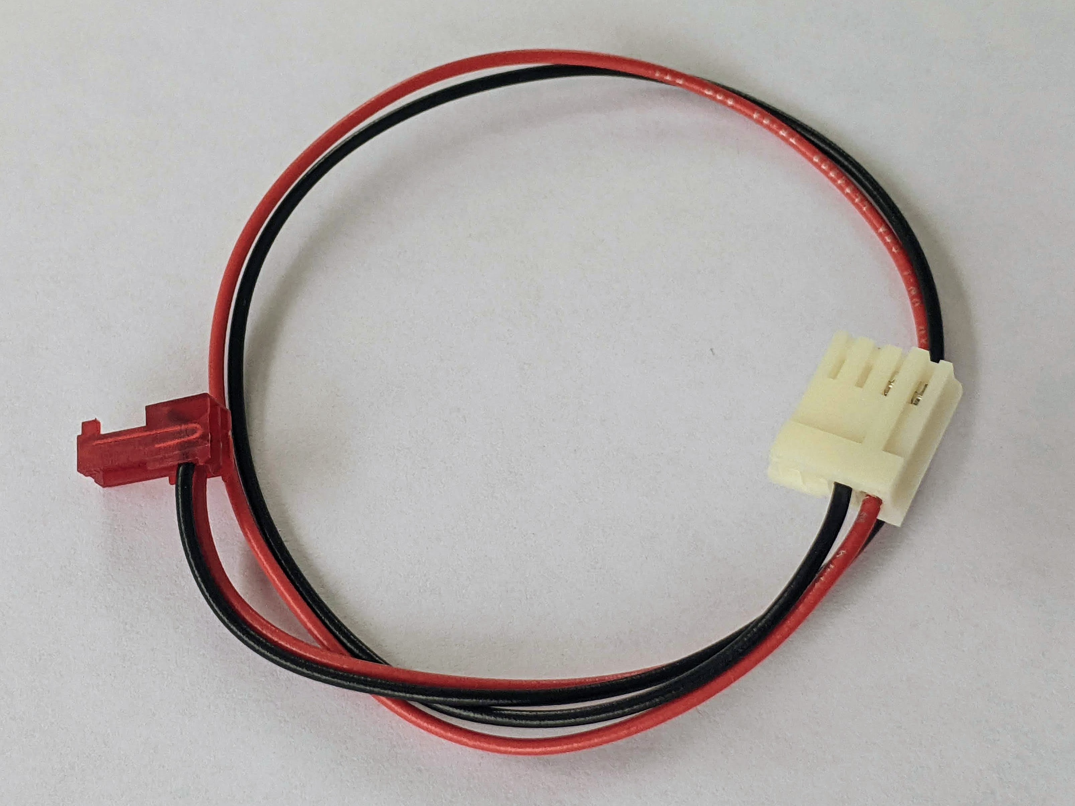
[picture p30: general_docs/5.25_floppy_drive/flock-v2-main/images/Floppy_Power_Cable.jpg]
Floppy power cable
                 |           | Floppy disk power cable                                | 1 (optional)

## Assembly Steps

### 1. Gather supplies and parts

* Check that you have all the equipment and parts listed in the [Prerequisites](#prerequisites) section above
* Organize your workspace. If available, use ESD-safe surface and ESD strap when working on this project

### 2. Solder the components

Solder the components to the PCB going from lower profile components to higher profile components, from smaller components to larger. Here is the recommended order:

* Start by soldering the R1 - R3 resistors. The resistors are not polarized and can be oriented either way. Trim the leads using cutters
* Next solder the Y1 and Y2 quartz crystals. Make a U-shaped loop using a resistor lead cut in the previous step, and secure Y2 to the PCB with that loop
* Solder RN1 resistor array. Make sure that the resistor array is oriented correctly. The first pin of the resistor array is marked with a printed dot, and the first pad on the board has a square shape
* Solder the C1 - C5, C8, and C9 capacitors. Note that these are non-polarized ceramic capacitors, so they can be oriented either way. Trim the leads using cutters
  * C1 – C5 have a “104” marking
  * C8 has “470” marking
  * C9 has “150” marking
* Solder DIP sockets for the U2 – U5 ICs. Double check the orientation of the sockets. The notch on the socket should match the notch on the PCB’s silkscreen.
Solder two opposite pins first, making sure that the socket sits flat on the PCB. Check the orientation and the alignment, fix as needed,
then solder the rest of the pins
  * Note that soldering the socket for U2 is optional. The real time clock would be more accurate without it,
as the socket introduces extra capacitance. You may choose to solder the DS1302 RTC IC directly to the PCB at this step
* Solder the PLCC socket for the U1 IC. Make sure that the cut side of the socket aligns with the drawing on the silkscreen
* Solder the J3 RCBus connector
* Solder the J2 floppy power connector. This connector is optional. You might choose to power the floppy drive(s) directly from the power supply instead
* Solder the J1 floppy interface connector
  * Note that you may need to cut or extract pin 3 from this connector to accommodate some floppy cables that have this pin position blocked
* Solder the JP1 header
* Solder the C6 capacitor. Pay attention to the __polarity__ – the negative side is painted white on the PCB and marked with blue on the capacitor. Note that C6 is marked as 47uF on the PCB. Install the supplied 10uF capacitor instead
* If a supercapacitor to be used for RTC backup, solder the C7 supercapacitor. Pay attention to the __polarity__ – the negative side is painted white on the PCB and marked with gray stripe on the supercapacitor. Note that C7 is marked as 0.22F on the PCB. Install the supplied 0.33F supercapacitor instead
* If a CR2032 battery to be used for RTC backup, solder BT1 battery holder. Observe the __polarity__

### 3. Check your soldering work

* Make sure all pins of all components are soldered properly
* If desired, clean the flux using isopropyl alcohol, cotton swabs. You might want to scrub the board lightly with a used toothbrush to remove the flux
* Check soldering work again after cleaning the board

### 4. Insert the integrated circuits to the sockets
* Prior to inserting DIP integrated circuits to the sockets board, bend their leads slightly, so they point 90 degrees downward. Put the IC on the side on a hard flat antistatic surface and gently push it down to bend the leads. Repeat on the other side of the IC
* Double check that you're placing the integrated circuit in the right socket, check the IC orientation. The index notch on the IC should match the notch on the socket and the drawing on the PCB's silkscreen
* To insert the 37C65 FDC integrated circuit in PLCC44 package, place it on the top of the socket, double check the orientation of the integrated circuit, and firmly push it down. It should click into the socket

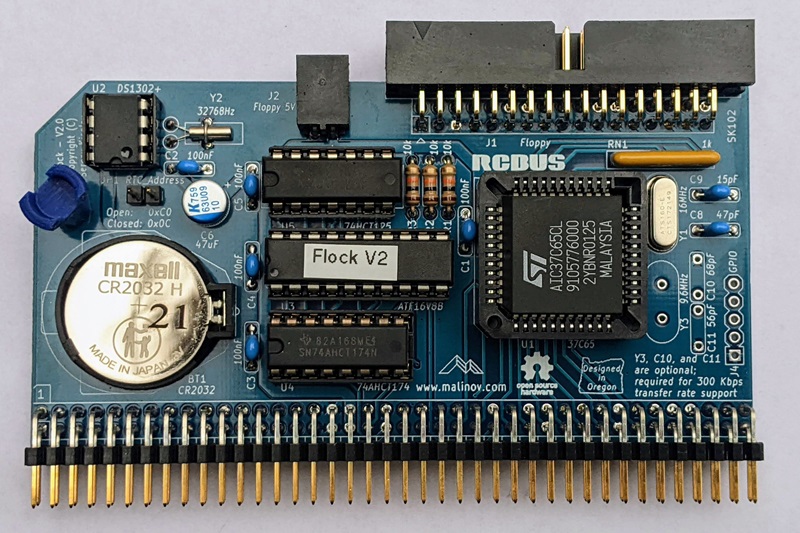
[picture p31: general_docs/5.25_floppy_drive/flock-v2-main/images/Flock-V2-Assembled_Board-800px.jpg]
Assembled board


## Module Installation Instructions

* Make sure that your RCBus or RC2014*-compatible system has I/O port range 0x48-0x5F available for the Floppy Disk Controller
* If you have a Z80-based system:
  * Make sure that jumper JP1 is **not** installed
  * Verify that I/O port range 0xC0-0xC1 is available
* If you have a Z180-base system:
  * Install jumper JP1
  * Verify that I/O port range 0x0C-0x0D is available
* Plug the module into your system
* Connect the floppy drive(s) to the board. Standard IBM PC ribbon floppy cable with twisted wires 10-16 should be used (not supplied). The first floppy drive is the one at the end of the cable, the second is on the middle of the cable
* Connect the floppy drive(s) to power supply. A single 3.5” 1.44 MB drive can be powered directly from the Flock board, using supplied power cable. Make sure to use powerful enough power supply. The floppy drive consumes about 1A
* Rebuild RomWBW with floppy support or use the pre-built image provided in the project’s GitHub repo. Here are the brief steps to rebuild the image. See [https://github.com/wwarthen/RomWBW/blob/master/Source/ReadMe.txt](https://github.com/wwarthen/RomWBW/blob/master/Source/ReadMe.txt) for complete instructons:
    a. Download the RomWBW source or clone its Git repository: [https://github.com/wwarthen/RomWBW/releases](https://github.com/wwarthen/RomWBW/releases)
  1. Open the _Source/HBIOS/Config/RCZ80_std.asm file_ in a text editor, and set _FDENABLE_ value to _TRUE_
  2. From the _Source_ folder, run the **BuildShared** command. This will build software that is shared by all RomWBW images
  3. From the _Source_ folder, run the **BuildRom** command. Select “RCZ80” platform and “std” configuration
  4. The resulting ROM image will be located in the Binary folder and will be named _RCZ80_std.rom_. Program the image to your systems’ flash ROM using either an EPROM programmer or FLASH4 command
* Power on your system. Verify that RomWBW shows DSRTC: device, reads the time from the RTC, shows FD: device, and displays floppy disk drives as shown in the screenshot below:

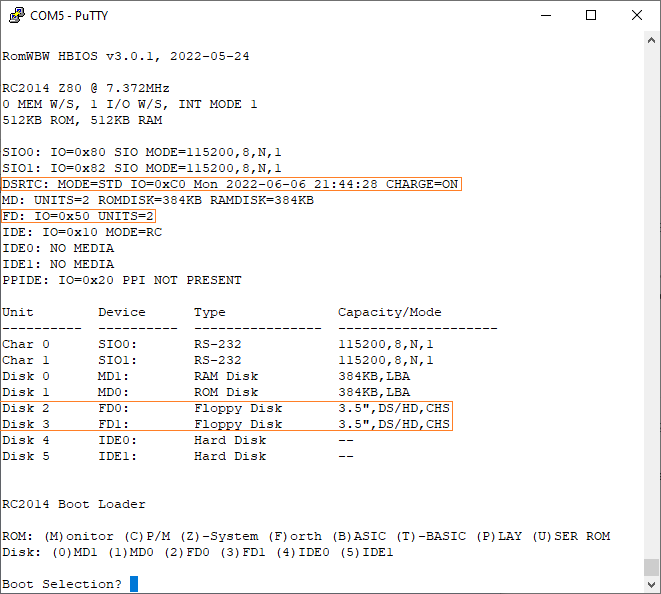
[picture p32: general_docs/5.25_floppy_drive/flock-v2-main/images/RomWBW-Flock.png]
RomWBW Boot Screen with Flock


## Module Usage Instructions – Floppy Disk Controller
The FDU utility included in RomWBW and can be used to test the floppy disk controller and to format floppy disks
* Boot your system to CP/M or ZSDOS and run the **FDU** command. Type **H** to select “(H) RC2014 WDC (SMB)”
* Use the **S** command to set the floppy disk configuration. Select the correct media type (e.g., enter “01” for 1.44 MB disks), leave the default settings for mode and trace
* Use the **F** command to format the floppy disk. Note that all information on the disk will be destroyed
* Use the **R** and **W** commands to test reading from and writing to the floppy disk
Once formatted, the floppy disk can be accessed from CP/M and ZSDOS. RomWBW normally assigns letters _C:_ and _D:_ to the first and the second floppy drives respectively

## Module Usage Instructions – FAT12 Floppy formatting
The FAT utility included with RomWBW will format floppies to FAT12, rendering them writable on modern computers.
* Boot your system to an OS which supports the FAT utility (I.E. ZP/M). 
* Observe the disk unit number when booting your system for FD0 (I.E. Disk 2)
* Run **FAT FORMAT 2:** and be absolutely sure your disk unit number is correct.  
* Wait for the format to complete.
Once formatted, the disk can be used with a modern computer, such as with a USB to 1.44 Floppy drive. The floppy disk can be accessed only using the FAT utility on RomWBW; Formatting a disk this way is primarily to use it for a bridge to a modern machine. The FAT utility is used to copy files between your CP/M etc. system storage, and the FAT formatted floppy disk.

## Module Usage Instructions – Real Time Clock
The RTC utility included in RomWBW is used to set and test the real time clock
* Boot your system to CP/M or ZSDOS and run the **RTC** command
* Use the **I** command to enter the current date and time. Use two digit values for each entry
* Use the **S** command to set the RTC to the time entered in the previous step with I command
* Use the **T** command to print the current time. Check that the time is set correctly and RTC properly updates the time
* Use the **C** command to enable trickle charge, so that DS1302 will be charing the on-board supercapacitor

__Congratulations! Enjoy your Flock Module!__

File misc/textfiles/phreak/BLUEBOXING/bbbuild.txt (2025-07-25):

                        ----------------------- 
                        How to build a BLUE BOX 
                        ----------------------- 
 
   We all know that the touch tone frequencies are composed of 2 tones (2 
different frequencies) so that is the reason why we have 2 VCO's (Voltage 
Controlled Oscilators). We will call then VCO#1 and VCO#2. If you have
noticed VCO#1 and VCO#2 are exactly the same type of circuits. That is why
only 1 was drawn. But remember that whatever goes for VCO#1 also goes for
VCO#2. Both VCO'S are composed of a handfull of part. One chip, two
capacitors, 2 resistors and five potentiometers. All of this will give you
(when properly calibrated) one of the freqencies necessary (the other one
will come from VCO#2) for the operation of the Blue Box. Both of these freqs.
will be mixed in the speaker to form the required tone. 
 
   This is one of the most sophisticated designs I have ever made. Why? 
Because other designs will drain the battery after 10 calls. This design will
make them last 10 months!!!!!  But never the less, don't forget to put in a
switch for on and off. Ok let's build the two VCO'S and calibrate the unit
before we get to the keyboard construction. 
 
VCO CONSTRUCTION: 
---------------- 
 
           TOOLS REQUIRED 
 
 1 ocilliscope(optional but not req) 
 1 Freq. counter   (REQUIRED) 
 1 Volt meter       "  "  " 
   Electronics tools  (Pliers,drll, 
   screwdrivers, etc.) 
 
===================================== 
 
               PARTS 
 
 R1  1.5K RESISTOR  5% 
 R2 1K	 RESISTOR  5%
 C1 .1uf ELECTROLYTIC CAPACITOR 16VDC 
 C2 .01uf    "        "  (MYLQR)16VDC 
IC1 2207 VCO CHIP BY EXAR ELECTRONICS 
    Remember the above only says 
    VCO#1 but the same is for VCO#2 
 R3-R4 150 OHM RESISTORS  5% 
 C3-C4 .1 uf ELECTROLITIC CAPACITOR 
       10VDC 
 P1-P10 200K TRIMMER POT - 20 TURNS 
       DIODES USED IN THE KEYBOARD 
       ARE 1N914 TYPE (40 OF THEM) & 
       13 SWITCHES FOR THE KEYBOARD 
       SPST MOMENTARY. 
 SPKR=YOU CAN USE A TELEPHONE SPEAKER 
      FOR THIS (IT WORKS BEST) BUT 
      REMEMBER TO TAKE OUT THE DIODE 

      THAT IS CONNECTED ACCROSS IT. 
 
======================================= 
 
           IMPORTANT NOTES 
 
  1. DO NOT USE ANYTHING ELSE OTHER 
     THAN A MYLAR CAPACITOR FOR C2. 
  2. PINS 10,9,8 SHOULD BE TIED 
     TOGETHER AND BE LEFT FLOATING. 
  3. ALL RESISTORS SHOULD BE 5%! 
     NOTHING ELSE! 
  4. A TELEPHONE SPEAKER GIVES THE 
     BEST RESULTS. 
 
======================================= 
 
           TROUBLE SHOOTING 
 
   By now you should have constructed the two VCO'S on a bread board or 
anything that pleases you. Check for cold solder joints, broken wires, 
polarity of the battery, etc. Before we apply power to the VCO'S we have to
adjust the pots for their half way travel point. This is done by turning them
21 turns to the right and then 10 turns to the left. Do the same for all ten
of them. 
 
   Now apply power to the unit check to see that you have power in the chips
by putting the positive lead of your volt meter on pin 7 and the negative
lead on pin 12. If you do not have anything there turn off the unit and
RECHECK THE WIRING. 
 
   When you get the right voltages on the chips, connect a diode to a piece
of wire (look at fig. 2 for the orientation of the diode) from ground to any
pot at point T (look carefully at the schematic for point T it is labeled
T1-T10 for all pots). You should be able to hear a tone, if not disconnect
the lead and place the speaker close to your ear and if you hear a chirp-like
sound, this means that the two VCO'S are working if you don't, it means that
either one or both of the VCO'S are dead. So in this case it is always good
to have an ocilloscope on hand. Disconnect the speaker from the circuit and
hook the ocilliscope to 1 of the leads of the speaker & the ground from the
scope to the ground of the battery. Connect again the ground lead with the
diode connected to it from ground to any pot on the VCO that you are checking
and you should see a triangle wave if not turn the pot in which you are
applying the ground to until you see it. When you do see it do the the same
for the other VCO to make sure it is working. (amplitude is about 2VAC). When
you get the two VCO's working you are set for the adjustment of the
individuals pots. 

                            Adjustment 
                            ---------- 
 
   Disconnect the speaker from the circuit and connect a freq. counter (the
positive lead of the counter to one of the speakers leads that belongs to 

VCO#1 or connect it to pin 14). 
 
   Connect the negative lead to the battery negative and connect the jumper
lead with the diode from ground to pot number 1.T1. ( the first pot number
1 point T1) if you got it working you should hear a tone and get a reading
on the counter. Adjust the pot for a freq. of 1700HZ and continue doing the
same for pots 2-5 except that they get differents freqs. which are: 
 
$$$$$$$$$$$$$$ 
$ P1= 1700hz $ 
$ P2= 1300hz $ 
$ P3= 1100hz $ 
$ P4=  900hz $ 
$ P5= 1500hz $ 
$$$$$$$$$$$$$$ 
 
   Now disconnect the freq. counter from the speaker lead of VCO#1 or from
pin 14 (which ever you had it attached to at the beginning) and connect it
to the speaker lead of VCO#2 or to pin 14 of VCO#2 and make the same
adjustments to P6-10. 
 
$$$$$$$$$$$$$$$ 
$ P6=  1100hz $ 
$ P7=   700hz $ 
$ P8=   900hz $ 
$ P9=  2600hz $ 
$ P10= 1500hz $ 
$$$$$$$$$$$$$$$ 
 
   When you finish doing all of the pots go back and re-check them. 

                            Keyboard 
                            -------- 
 
  If you look at FIG-2 you will see that the keys are simple switches. 
Connected to a ground and two diodes on the other end. these diodes are used
to simplify the construction of the keyboard because otherwise the
distribution of the ground signal for both VCO'S would have been done
mechanically. The diode will go to VCO#1 and the other will go to VCO#2.
FIG-3 shows the arrangement of the keys on the keyboard. 

   Below is a table that will help you connect the keys to the required VCO's
pots. 
 
              (-FIG 2-)               
-----!-----!--------!--------!------- 
     !     !        !        !        
 TO  ! TO  !  FREQ  !  FREQ  !  KEY   
 POT ! POT !  OUT:  !  OUT:  !        
 ON  ! ON  !        !        !        
 VCO1! VCO2!        !        !        
-----!-----!--------!-------%!------- 

  1  !  06 ! 1700hz ! 1100hz !   C 
  2  !  10 ! 1300hz ! 1500hz !   0 
  1  !  10 ! 1700hz ! 1100hz !   E 
  4  !  07 ! 0900hz ! 0700hz !   1 
  3  !  07 ! 1100hz ! 0700hz !   2 
  3  !  08 ! 1100hz ! 0900hz !   3 
  2  !  07 ! 1300hz ! 0700hz !   4 
  2  !  08 ! 1300hz ! 0900hz !   5 
  2  !  06 ! 1300hz ! 1100hz !   6 
  5  !  07 ! 1500hz ! 0700hz !   7 
  5  !  08 ! 1500hz ! 0900hz !   8 
  5  !  06 ! 1500hz ! 1100hz !   9 
  -  !  09 ! ------ ! 2600hz !   X 
 
   Remember that in FIG-2 it's the same for each key except the "X" key,
which only takes one diode. 

few KEYS to the diagram: 
 
Cx is capacitor #x   Denoted by: ---| | 
--- 
 
Px is Pot or Variable resistor #x  Deno 
ted by :/ 
 
        \ 
 
        /<--   
                                    \ 
Rx is resistor #x  Denoted by /\/\/\/\ 
 
                            SCHEMATICS 
 
     The XR-2207 chip is a Voltage-Controlled Oscillator and a 14 pin device
thus you must be very careful when soldering the parts to this device. It is 
a little dificult to actually draw a schematic on an 80 character screen  
using limited graphics, but I will give 
it a try. 
 
                                        TO GND_____________ 
                                              | 
                                                         ___ 
                                               C2     C3 ___ 
                                            _||_          | 
                                           |    |    _____|__9v+ 
                                           |    |    |    | 
                        `   `    `    `    `    `    `    | 
                        -------------------------------   | 
                        7   6    5    4    3    2    1 |  | 
                       |                               <  | 
                       |8   9    10   11   12   13   14|  | 
                        -------------------------------   | 
                        `   `    `    `    `    `    `    | 

                                 |    |                   | 
                    --| |--------|    |                   | 
                    |C1    R2         |         R1        | 
          GND ______|___/\/\/\/\______|_____/\/\/\/\______| 

is is a diagram of how to locate the different pins on the chip. 
Please notice that pin one (1) is the closest to the notch on top of the
chip. The first thing we'll do is to connect power to the chip (remember that
you need to build two (2) of these to get a complete system) this is
accomplished by connecting the positive wire of the battery lead to pin#1 one
leg of R1  and R2 is soldered to pin#11. The other leg of R1 goes to pin 1
or to the d. C1 goes between pin 10 and ground. The timing capacitor or C2
goes between pins 2 and 3 of the chip. Pins 8 and 9 should be grounded to
ground. Pin 14 is the output and this is where one leg of C4 (C3 goes on the
other VCO) in series with R3 (the same goes for the other VCO) and to one
lead of the speaker. 
 
     The trimmer pots P1 to P10 should be grouped in groups of 5 pots each.
The way you group it is by soldering one end of the pot to each other leaving
the wiper and the other end free. 
 
          | This end goes to pin 6 of the chip 
                   | 
      _____________|_____________ 
       /     /     /     /     / 
       \     \     \     \     \ 
       /<-   /<-   /<-   /<-   /<- 
       \ |   \ |   \ |   \ |   \ |  
       / |   / |   / |   / |   / | 
         |     |     |     |     | 
         |     |     |     |     | 
       P1      P2    P3    P4    P5 

     And finally this is the way each key should be wired. 
 
                 diode 
he contact of  the  
                         |--------- \------               key 
     to Px  ------>|-----|                | 
                 diode                    | 
                                        ----- 
                                         --- Ground

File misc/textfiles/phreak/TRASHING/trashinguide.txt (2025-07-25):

                                                        \Anti-Social Magazine
                                                         \  Issue 12 31/03/99
                                                          +------------------
                           =====================
                           Trashing - The Guide
                                 By Crashd
                           =====================

Hey, Nice to be back again, This is my first interesting file in a long time,
And as far as I can tell (sorry if I'm wrong) this subject hasnt been covererd
at all (for the UK) Although I remeber some rather amusing incidents involving
trash :) Trashing, is basically just wading through bags of shit and rubbish,
looking for interesting things - documents, flopwarez, equipment etc..

This deal is split into 2 main areas, personal and business (just like the BT
phone book :)

Ok, i'm gonna deal with personal first, as this is probably the easiest.

1.\ Personal Trashing
=====================

Let's take target #1. He's maybe a businessman, you want his CC number,
mobile ESN, Girlfriends phone number, or just want to invade on the poor man's
private life.  Well the best place to start, is find his home address, and
preferably the post code (if you cant find the latter, just knock at the few
houses around his, they will probably glady give you it, lie and say your new
to the neighbourhood) Now, phone the local council dude's, and ask when the
refuse collectors (garbage men :) pick up the trash/shit. Or just ask the
nice neighbours again.

The Night before the trash pick-up, be prepared.  For clothes, I recommend
something warm, this is my standard atire:

* 1 heavy-duty flashlight
* 1 backpack lined with binbag
* 1 black beanie hat
* 1 pair of gardeners gloves
* 1 pair of latex gloves
* 1 Pair of lightweight bottoms
* 1 rain-coat, just in case

Now, go for a stroll, probably the best time is about 10 or 11. Walk past the
person's house, and check to see if he/she has left out their groovy wheely
bin (most houses in the UK have these, a gift from the Labour Government).
If so, walk straight past, towards say a shop or phone box, or whatever.
About 10 minutes later, stroll past again, and accidently shunt into the bin,
pick it up off of the ground, and walk away with it, take it down a
back-street or whatever.  Open it up, and get searching, dont forget the
flashlight, dont shine it into cars going past or whatever. If you see
anything worth stealing, pop it into your nice bag.
Common stuff for stealing is:

* Phone Bill
* Receipts
* Business Cards
* Filo-Fax's
* Diary's (blackmail anyone?)

Most people tend not to chuck out Tv's etc..but if you find any electronical
junk, take it and salvage for components :) When your finished with this bin,
walk past nice and calm, make the drop off, turn a corner and walk slowly
home, along with your sack of delights :)

2.\ Business Trashing
=====================

Business Trashing is much more popular than the latter shit. Stuff you can
get from Companies include:

* Big Lists of ESN's
* Manuals for Computers etc..
* Journals (par example, the first Blue Box was derived from a technical
  manual found in a bin in the US) [Correction, No it wasn't, it was built
                                    using the tones published in a technical
                                    journal, publically available though
                                    not a well distributed one -Ed]
* Equipment no longer needed

Hmm, the atire should basically remain the same, nice and conspicous and most
of all old - it will take a little more than vanish to get rid of that Bad
smell :)

The only time to trash business's is at NIGHT. Make it a weekend (maybe friday
or saturday).  Walk past Target company at about 10 to check out any security
measures that may harras you, such as watchmen, dog's or camera's.  (A
favourite target of UK phreakers is BT's Exchanges/Offices.  A lot of the MED
archives is supposedly found through trashing =) Pop back to your house and
pick up any decoy's or help you may need:

Example:

* Dog's - Mace (cruel) some fresh bloddy dripping meat (nice, but expensive
          and short term)
              OR
          An Ultrasonice grenade (Schematic shown below..it works as
          well...damn good.

* Camera's - Spray paint (good), blakck paper or just wear a lot of black and
             hope to hell they aint infra-red.
             
* Watchmen - You will almost certainly need some friends to help, get them to
             either phone the place in question, or create a decoy, ie:
             harrasing him while you nip round the back.

Also, bring the bag, in it put some chain cutters, and a crowbar.

If there is chains, cut them. A door? Crowbars work wonders.
Once past the first obstacle, if there any of the above (dog, camera's etc..)
If it is a yard etc.. the bins are big green/grey plastic/metal effors,
probably chained, cut the chains and get rooting, try to have a look-out
keeping tabs for you.

Obvious items of interest (from experience in BT places) are:
* Big Chunks Manuals
* Any Reams of form-feed paper (usually phone bills or quotes)
* ANY Equipment, electrical or otherwise

Now, your trashing mission is complete, try and escape a different way to
your way of entry, and if you disturbed anything, for example the camera's,
leave them, Looks better in the long run.

If you repeat trash a place You will probably get caught quickly, sorry but
that's the long and short of it, so go trashing maybe once every 2 months,
and make it a nice big thorough inspection as you aint coming back for a
while

* Schematics For Ultrasonic grenade.
====================================

Ok, here's what you will need:

* 1 Gutted Tennis Ball
* Circuit Board - Bread-Board will do for this.
* 1 Ultrasonic Transducer (sender, not receiver), (Maplin, rapid, about ú1)
* 1 555 Timer chip
* 2 resistors, preferably variable
* 2 capacitors - .1 Muf should do.
* 1 Mercury Tilt Switch
* 1 1 Normal SPDT switch

Ok, first, if you Cant set up a monostable timing circuit, please please
please dont bother trying to build this. Go check the web or ask a
electronics lecturer.  Ok, for the input of the timing circuit(Chip's pin 1),
we want the mercury tilt switch, these are bi-polar. Have the timing circuit
on it's own little PCB, and between then battery and the circuit, have the
normal SPDT switch, cut out a small hole for this on the tennis ball. Also
cut out another one, about 2cm's in diameter, for our transducer. Now wire
the ultrasonice transducer as the output (pin 3) of the timing circuit. Glue
the transducer into the tennis ball, and close it up with a bit of
araldite/black tape/whatever.

Operation
=========

When you want to use this, throw the SPDT switch, and lob it at a wall, make
sure that it spins, or at least rolls. No dog/cat/bat for a good few meter's
will be able to come near it and if they do, they will be in a little pain.

IF you want the Proper PCB Schematics and FULL instructions for this (yes,
even how to build the fucking timer circuit) mail: crash_dave_1997@yahoo.com

Ok, thanks for reading, and if you havent..you've missed it all :)
Werd
Mail me:
crash_dave_1997@yahoo.com
ICQ UIN: 7538027
IRC: EFNET: #2600-uk, #phuk

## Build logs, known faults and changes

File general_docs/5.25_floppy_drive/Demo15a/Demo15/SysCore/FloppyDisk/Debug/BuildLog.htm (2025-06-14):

Build Log

| | Build started: Project: FloppyDisk, Configuration: Debug|Win32

Command Lines

Creating temporary file "c:\djgpp\Demo15\SysCore\FloppyDisk\Debug\RSP00003351682788.rsp" with contents
[
/Ox /Oy /I "..\Include\\" /D "ARCH_X86" /X /FD /EHsc /MT /Zp1 /GS- /GR- /FAs /Fa"Debug\\" /Fo"Debug\\" /Fd"Debug\vc80.pdb" /W4 /c /TP .\flpydsk.cpp
]
Creating command line "cl.exe @c:\djgpp\Demo15\SysCore\FloppyDisk\Debug\RSP00003351682788.rsp /nologo /errorReport:prompt"
Creating temporary file "c:\djgpp\Demo15\SysCore\FloppyDisk\Debug\RSP00003451682788.rsp" with contents
[
/OUT:"C:\djgpp\Demo15\SysCore\Debug\FloppyDisk.lib" .\Debug\flpydsk.obj
]
Creating command line "lib.exe @c:\djgpp\Demo15\SysCore\FloppyDisk\Debug\RSP00003451682788.rsp /NOLOGO"

Output Window

Compiling...
flpydsk.cpp
.\flpydsk.cpp(349) : warning C4244: 'argument' : conversion from 'uint32_t' to 'uint8_t', possible loss of data
.\flpydsk.cpp(365) : warning C4244: 'argument' : conversion from 'uint32_t' to 'uint8_t', possible loss of data
.\flpydsk.cpp(367) : warning C4244: 'argument' : conversion from 'uint32_t' to 'uint8_t', possible loss of data
.\flpydsk.cpp(385) : warning C4244: 'argument' : conversion from 'uint32_t' to 'uint8_t', possible loss of data
.\flpydsk.cpp(480) : warning C4244: 'argument' : conversion from 'uint32_t' to 'uint8_t', possible loss of data
.\flpydsk.cpp(481) : warning C4244: 'argument' : conversion from 'uint32_t' to 'uint8_t', possible loss of data
.\flpydsk.cpp(552) : warning C4244: 'argument' : conversion from 'int' to 'uint8_t', possible loss of data
.\flpydsk.cpp(552) : warning C4244: 'argument' : conversion from 'int' to 'uint8_t', possible loss of data
.\flpydsk.cpp(552) : warning C4244: 'argument' : conversion from 'int' to 'uint8_t', possible loss of data
Creating library...

Results

| | Build log was saved at "file://c:\djgpp\Demo15\SysCore\FloppyDisk\Debug\BuildLog.htm" FloppyDisk - 0 error(s), 9 warning(s)

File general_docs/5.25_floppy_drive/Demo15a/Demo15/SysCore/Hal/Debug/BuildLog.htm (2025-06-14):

Build Log

| | Rebuild started: Project: Hal, Configuration: Debug|Win32

Command Lines

Creating temporary file "c:\djgpp\Demo15\SysCore\Hal\Debug\RSP0000244164608.rsp" with contents
[
/Ox /Oy /I "..\Include\\" /D "ARCH_X86" /X /FD /MT /Zp1 /GS- /GR- /Fo"Debug\\" /Fd"Debug\vc80.pdb" /W4 /c /TP .\pit.cpp

.\pic.cpp

.\idt.cpp

.\Hal.cpp

.\gdt.cpp

.\cpu.cpp
]
Creating command line "cl.exe @c:\djgpp\Demo15\SysCore\Hal\Debug\RSP0000244164608.rsp /nologo /errorReport:prompt"
Creating temporary file "c:\djgpp\Demo15\SysCore\Hal\Debug\RSP0000254164608.rsp" with contents
[
/OUT:"C:\djgpp\Demo15\SysCore\Debug\Hal.lib" .\Debug\cpu.obj

.\Debug\gdt.obj

.\Debug\Hal.obj

.\Debug\idt.obj

.\Debug\pic.obj

.\Debug\pit.obj
]
Creating command line "lib.exe @c:\djgpp\Demo15\SysCore\Hal\Debug\RSP0000254164608.rsp /NOLOGO"

Output Window

| | Compiling... pit.cpp pic.cpp idt.cpp Hal.cpp gdt.cpp cpu.cpp Generating Code... Creating library...

Results

| | Build log was saved at "file://c:\djgpp\Demo15\SysCore\Hal\Debug\BuildLog.htm" Hal - 0 error(s), 0 warning(s)

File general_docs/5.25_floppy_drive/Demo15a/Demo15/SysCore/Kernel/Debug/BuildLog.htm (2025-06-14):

Build Log

| | Build started: Project: Kernel, Configuration: Debug|Win32

Command Lines

Creating temporary file "c:\djgpp\Demo22\Demo15\Demo15\SysCore\Kernel\Debug\RSP00000110282092.rsp" with contents
[
/O2 /Oy /I "..\Include\\" /I "..\Keyboard" /I "..\FloppyDisk" /D "ARCH_X86" /X /FD /MT /Zp1 /GS- /GR- /Fo"Debug\\" /Fd"Debug\vc80.pdb" /W4 /c /Gd /TP /Oy

.\mmngr_virtual.cpp

.\main.cpp
]
Creating command line "cl.exe @c:\djgpp\Demo22\Demo15\Demo15\SysCore\Kernel\Debug\RSP00000110282092.rsp /nologo /errorReport:prompt"
Creating temporary file "c:\djgpp\Demo22\Demo15\Demo15\SysCore\Kernel\Debug\RSP00000210282092.rsp" with contents
[
/OUT:"A:\KRNL32.EXE" /INCREMENTAL:NO /LIBPATH:"..\Lib\\" /LIBPATH:"..\debug\\" /MANIFEST:NO /NODEFAULTLIB /MAP:"Kernel.map" /SUBSYSTEM:NATIVE /DRIVER /OPT:REF /OPT:ICF /ENTRY:"kernel_entry" /BASE:"0xC0000000" /FIXED:No /ALIGN:512 keyboard.lib floppydisk.lib "..\debug\lib.lib" "..\debug\hal.lib"

".\Debug\entry.obj"

".\Debug\main.obj"

".\Debug\DebugDisplay.obj"

".\Debug\exception.obj"

".\Debug\mmngr_phys.obj"

".\Debug\mmngr_virtual.obj"

".\Debug\panic.obj"

".\Debug\Resource.res"

".\Debug\vmmngr_pde.obj"

".\Debug\vmmngr_pte.obj"
]
Creating command line "link.exe @c:\djgpp\Demo22\Demo15\Demo15\SysCore\Kernel\Debug\RSP00000210282092.rsp /NOLOGO /ERRORREPORT:PROMPT"

Output Window

| | Compiling... mmngr_virtual.cpp main.cpp .\main.cpp(62) : warning C4244: 'argument' : conversion from 'uint64_t' to 'size_t', possible loss of data .\main.cpp(266) : warning C4127: conditional expression is constant Generating Code... c:\djgpp\demo22\demo15\demo15\syscore\kernel\main.cpp(295) : warning C4702: unreachable code Linking... lib.lib(cstd.obj) : warning LNK4254: section '.CRT' (40000040) merged into '.data' (C0000040) with different attributes

Results

| | Build log was saved at "file://c:\djgpp\Demo22\Demo15\Demo15\SysCore\Kernel\Debug\BuildLog.htm" Kernel - 0 error(s), 4 warning(s)

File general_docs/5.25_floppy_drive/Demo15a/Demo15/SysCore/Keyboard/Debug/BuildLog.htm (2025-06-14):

Build Log

| | Build started: Project: Keyboard, Configuration: Debug|Win32

Command Lines

Creating temporary file "c:\djgpp\Demo15\SysCore\Keyboard\Debug\RSP00001B51684540.rsp" with contents
[
/O2 /Oy /I "..\Include\\" /D "ARCH_X86" /X /FD /EHsc /MT /Zp1 /GS- /GR- /Fo"Debug\\" /Fd"Debug\vc80.pdb" /W4 /c /TP .\kybrd.cpp
]
Creating command line "cl.exe @c:\djgpp\Demo15\SysCore\Keyboard\Debug\RSP00001B51684540.rsp /nologo /errorReport:prompt"
Creating temporary file "c:\djgpp\Demo15\SysCore\Keyboard\Debug\RSP00001D51684540.rsp" with contents
[
/OUT:"C:\djgpp\Demo15\SysCore\Debug\Keyboard.lib" .\Debug\kybrd.obj
]
Creating command line "lib.exe @c:\djgpp\Demo15\SysCore\Keyboard\Debug\RSP00001D51684540.rsp /NOLOGO"

Output Window

Compiling...
kybrd.cpp
..\Include\ctype.h(39) : warning C4005: 'isascii' : macro redefinition
..\Include\ctype.h(28) : see previous definition of 'isascii'
.\kybrd.cpp(260) : warning C4127: conditional expression is constant
.\kybrd.cpp(277) : warning C4127: conditional expression is constant
.\kybrd.cpp(485) : warning C4806: '|' : unsafe operation: no value of type 'bool' promoted to type 'int' can equal the given constant
.\kybrd.cpp(485) : warning C4806: '&' : unsafe operation: no value of type 'bool' promoted to type 'int' can equal the given constant
.\kybrd.cpp(486) : warning C4806: '|' : unsafe operation: no value of type 'bool' promoted to type 'int' can equal the given constant
.\kybrd.cpp(486) : warning C4806: '&' : unsafe operation: no value of type 'bool' promoted to type 'int' can equal the given constant
.\kybrd.cpp(645) : warning C4127: conditional expression is constant
Creating library...

Results

| | Build log was saved at "file://c:\djgpp\Demo15\SysCore\Keyboard\Debug\BuildLog.htm" Keyboard - 0 error(s), 8 warning(s)

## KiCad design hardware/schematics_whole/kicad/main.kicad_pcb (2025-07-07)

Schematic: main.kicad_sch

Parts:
ALU_HIGH1: 74181N; DIP-24_W7.62mm
ALU_LOW1: 74181N; DIP-24_W7.62mm
BIOS_ROM1: 27512; DIP-28_W15.24mm
C1: C; C_Disc_D7.5mm_W4.4mm_P5.00mm
DIS1, DIS2: TIL311
FLAGS1: 74273N; DIP-20_W7.62mm
IC1, IC2, IC36, IC42, IC54, IC55, IC56, IC57, IC58, IC59, IC60, IC61, IC62, IC63, IC64, IC65, IC66, IC67, IC68, IC69, IC70, IC71, IC72, IC73, IC74, IC84, IC85, IC114, IC195: 74377N; DIP-20_W7.62mm
IC3, IC4, IC5, IC6, IC31, IC32, IC33, IC34: 74253N; DIP-16_W7.62mm
IC7, IC8, IC9, IC10, IC14, IC17, IC18, IC77, IC78, IC79, IC80, IC81, IC82, IC83, IC87, IC89, IC166, IC167, IC168, IC169: 74153N; DIP-16_W7.62mm
IC11, IC12, IC15, IC16, IC19, IC20, IC24, IC25, IC26, IC27, IC30, IC76, IC93, IC111, IC112, IC155, IC156, IC157, IC158, IC159, IC160, IC190, IC191: 74257N; DIP-16_W7.62mm
IC13, IC35, IC161: 7408N; DIP-14_W7.62mm
IC21, IC43, IC113, IC121, IC163, IC194: 7404N; DIP-14_W7.62mm
IC22, IC91, IC92, IC94, IC95, IC96, IC97, IC98, IC99, IC100, IC101, IC102, IC103, IC104, IC105, IC106, IC107, IC108: 74273N; DIP-20_W7.62mm
IC23: 7410N; DIP-14_W7.62mm
IC28, IC49, IC50, IC88, IC90, IC123, IC124, IC125, IC126, IC127, IC128, IC129, IC130, IC131, IC132, IC133, IC134, IC135, IC136, IC137, IC138, IC139, IC140, IC141, IC142, IC143, IC144, IC145, IC146, IC147, IC148, IC149, IC150, IC151, IC152, IC153, IC154: 74151N; DIP-16_W7.62mm
IC29, IC53: 7432N; DIP-14_W7.62mm
IC37: 7486N; DIP-14_W7.62mm
IC38, IC39, IC40, IC41: 74283N; DIP-16_W7.62mm
IC44, IC45, IC48, IC171, IC188, IC192: 7432N; DIP-14_W7.62mm; MPN SN7432N
IC46, IC52: 7400N; DIP-14_W7.62mm
IC47, IC115, IC117, IC118, IC119, IC120, IC172, IC173, IC174, IC179, IC180, IC185, IC186, IC196, IC197, IC198, IC200, IC202, IC204, IC206: 74244N; DIP-20_W7.62mm
IC51, IC109, IC165: 7427N; DIP-14_W7.62mm
IC75: 7411N; DIP-14_W7.62mm
IC86, IC116, IC176, IC199: 74138N; DIP-16_W7.62mm
IC110: 74245N; DIP-20_W7.62mm
IC122: 7420N; DIP-14_W7.62mm
IC162: 7430N; DIP-14_W7.62mm
IC164, IC170: 7474N; DIP-14_W7.62mm
IC175, IC187: 74279N; DIP-16_W7.62mm
IC177, IC178: 58C256P; DIP-28_W15.24mm
IC181, IC182, IC183, IC184: 74157N; DIP-16_W7.62mm
IC189, IC193, IC201: DIL14
IC_02_1: 7402N; DIP-14_W7.62mm
IC_04_1: 7404N; DIP-14_W7.62mm
IC_10_1, IC_10_2: 7410N; DIP-14_W7.62mm
IC_86_1, IC_86_2: 7486N; DIP-14_W7.62mm
IRQ_0_DFF1, IRQ_1_DFF1, IRQ_2_DFF1, IRQ_3_DFF1: 7474N; DIP-14_W7.62mm
IRQ_AND_1, IRQ_AND_2: 7408N; DIP-14_W7.62mm
IRQ_CODE1: 74377N; DIP-20_W7.62mm
IRQ_ENCODER1: 74148N; DIP-16_W7.62mm
IRQ_RST_DECODER1: 74138N; DIP-16_W7.62mm
IRQ_STATUS_1: 74273N; DIP-20_W7.62mm
J1: Conn_02x17_Odd_Even
MARH1: 74377N; DIP-20_W7.62mm
MARL1: 74377N; DIP-20_W7.62mm
MDRH1: 74377N; DIP-20_W7.62mm
MDRL1: 74377N; DIP-20_W7.62mm
MDR_IN_MUX_1, MDR_IN_MUX_2: 74157N; DIP-16_W7.62mm
MDR_OUT_MUX_1, MDR_OUT_MUX_2: 74157N; DIP-16_W7.62mm
PIO_0: 8255; DIP-40_W15.24mm
RN1, RN2, RN3, RN4, RN5, RN6, RN7, RN8, RN9: R_Pack08; DIP-16_W7.62mm
S1: 100SP1T1B4M2QE; SW_100SP1T1B4M2QE; PARTREV E
SW1, SW11, SW12, SW13: SW_SPST; SW_100SP1T1B4M2QE
SW2, SW4, SW5, SW6, SW7, SW8, SW9, SW10: SW_DIP_x08; DIP-16_W7.62mm
U1, U2, U3, U4, U5, U6, U7, U8: as6c4008-55pcn; DIP-32_W15.24mm
U9: M48T02-200PC1; DIP-24_W15.24mm
U10: 8253; DIP-24_W15.24mm
U11: 74LS06
U12: 74LS377
U13, U14: 16550; DIP-40_W15.24mm
U15: KM62256CLP; DIP-28_W15.24mm
U16: 4040; DIP-16_W7.62mm
U17, U19, U21, U35: 74HC04; DIP-14_W7.62mm
U18: 74LS173; DIP-16_W7.62mm
U20: 74LS244
U22: 74HCT244
U_ROM1, U_ROM2, U_ROM3, U_ROM4, U_ROM5, U_ROM6, U_ROM7, U_ROM8, U_ROM9, U_ROM10, U_ROM11, U_ROM12, U_ROM13, U_ROM14, U_ROM15: 27512; DIP-28_W15.24mm
WD1: (no value)
X1: ACO-10MHz; Oscillator_DIP-14
X2: 8mhz_osc; Oscillator_DIP-14
esp8266: (no value)

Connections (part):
/ah0: IC55.2 (1Q), IC123.3 (D1)
/ah1: IC55.5 (2Q), IC127.3 (D1)
/ah2: IC55.6 (3Q), IC131.3 (D1)
/ah3: IC55.9 (4Q), IC135.3 (D1)
/ah4: IC55.12 (5Q), IC139.3 (D1)
/ah5: IC55.15 (6Q), IC143.3 (D1)
/ah6: IC55.16 (7Q), IC147.3 (D1)
/ah7: IC55.19 (8Q), IC151.3 (D1)
/al0: IC54.2 (1Q), IC123.4 (D0)
/al1: IC54.5 (2Q), IC127.4 (D0)
/al2: IC54.6 (3Q), IC131.4 (D0)
/al3: IC54.9 (4Q), IC135.4 (D0)
/al4: IC54.12 (5Q), IC139.4 (D0)
/al5: IC54.15 (6Q), IC143.4 (D0)
/al6: IC54.16 (7Q), IC147.4 (D0)
/al7: IC54.19 (8Q), IC151.4 (D0)
/alu_cf: ALU_HIGH1.16 (CN+4), IC_86_1.5 (I1)
/alu_final_cf: IC18.5 (1C1), IC88.3 (D1), IC_86_1.6 (O)
/alu_of: IC20.3 (1B), IC90.3 (D1), IC_04_1.4 (O)
/alu_output_0: ALU_LOW1.9 (F0), IC18.4 (1C2), IC28.1 (D3), IC31.6 (1C0), IC31.12 (2C2), IC88.2 (D2)
/alu_output_1: ALU_LOW1.10 (F1), IC31.5 (1C1), IC31.10 (2C0), IC32.4 (1C2)
/alu_output_2: ALU_LOW1.11 (F2), IC31.11 (2C1), IC32.6 (1C0), IC32.12 (2C2)
/alu_output_3: ALU_LOW1.13 (F3), IC32.5 (1C1), IC32.10 (2C0), IC33.4 (1C2)
/alu_output_4: ALU_HIGH1.9 (F0), IC32.11 (2C1), IC33.6 (1C0), IC33.12 (2C2)
/alu_output_5: ALU_HIGH1.10 (F1), IC33.5 (1C1), IC33.10 (2C0), IC34.4 (1C2)
/alu_output_6: ALU_HIGH1.11 (F2), IC33.11 (2C1), IC34.6 (1C0), IC34.12 (2C2)
/alu_output_7: ALU_HIGH1.13 (F3), IC18.3 (1C3), IC28.15 (D4), IC31.3 (1C3), IC31.13 (2C3), IC32.3 (1C3), IC32.13 (2C3), IC33.3 (1C3), IC33.13 (2C3), IC34.3 (1C3), IC34.5 (1C1), IC34.10 (2C0), IC34.13 (2C3), IC88.15 (D4)
/alu_zf: IC13.1 (I0), IC17.5 (1C1), IC75.3 (I0), IC75.12 (O), IC87.5 (1C1)
/any_interruption: IC13.10 (I1), IC29.6 (O)
/bh0: IC57.2 (1Q), IC123.1 (D3)
/bh1: IC57.5 (2Q), IC127.1 (D3)
/bh2: IC57.6 (3Q), IC131.1 (D3)
/bh3: IC57.9 (4Q), IC135.1 (D3)
/bh4: IC57.12 (5Q), IC139.1 (D3)
/bh5: IC57.15 (6Q), IC143.1 (D3)
/bh6: IC57.16 (7Q), IC147.1 (D3)
/bh7: IC57.19 (8Q), IC151.1 (D3)
/bios_config: IC116.7 (Y7)
/bl0: IC56.2 (1Q), IC123.2 (D2)
/bl1: IC56.5 (2Q), IC127.2 (D2)
/bl2: IC56.6 (3Q), IC131.2 (D2)
/bl3: IC56.9 (4Q), IC135.2 (D2)
/bl4: IC56.12 (5Q), IC139.2 (D2)
/bl5: IC56.15 (6Q), IC143.2 (D2)
/bl6: IC56.16 (7Q), IC147.2 (D2)
/bl7: IC56.19 (8Q), IC151.2 (D2)
/bph0: IC67.2 (1Q), IC124.1 (D3)
/bph1: IC67.5 (2Q), IC128.1 (D3)
/bph2: IC67.6 (3Q), IC132.1 (D3)
/bph3: IC67.9 (4Q), IC136.1 (D3)
/bph4: IC67.12 (5Q), IC140.1 (D3)
/bph5: IC67.15 (6Q), IC144.1 (D3)
/bph6: IC67.16 (7Q), IC148.1 (D3)
/bph7: IC67.19 (8Q), IC152.1 (D3)
/bpl0: IC66.2 (1Q), IC124.2 (D2)
/bpl1: IC66.5 (2Q), IC128.2 (D2)
/bpl2: IC66.6 (3Q), IC132.2 (D2)
/bpl3: IC66.9 (4Q), IC136.2 (D2)
/bpl4: IC66.12 (5Q), IC140.2 (D2)
/bpl5: IC66.15 (6Q), IC144.2 (D2)
/bpl6: IC66.16 (7Q), IC148.2 (D2)
/bpl7: IC66.19 (8Q), IC152.2 (D2)
/buffered_mem_io: IC113.5 (I), IC122.1 (I0), IC176.4 (G2A), IC176.5 (G2B), IC197.14 (Y3), IC_10_2.11 (I2)
/buffered_rd_memory: IC197.12 (Y4), U1.24 (OE), U2.24 (OE), U3.24 (OE), U4.24 (OE), U5.24 (OE), U6.24 (OE), U7.24 (OE), U8.24 (OE)
/buffered_wr_memory: IC197.9 (Y1), U1.29 (WE), U2.29 (WE), U3.29 (WE), U4.29 (WE), U5.29 (WE), U6.29 (WE), U7.29 (WE), U8.29 (WE)
/bus_rd: IC186.18 (Y1), IC196.18 (Y1), IC197.2 (A1), IC197.8 (A4)
/bus_tristate: IC109.1 (I0), IC117.1 (G), IC117.19 (G), IC118.1 (G), IC118.19 (G), IC119.1 (G), IC119.19 (G), IC120.1 (G), IC155.1 (~A/B), IC156.1 (~A/B), IC192.6 (O), IC194.9 (I), IC196.1 (G)
/bus_wr: IC186.16 (Y2), IC196.16 (Y2), IC197.4 (A2), IC197.11 (A1)
/ch0: IC59.2 (1Q), IC123.14 (D5)
/ch1: IC59.5 (2Q), IC127.14 (D5)
/ch2: IC59.6 (3Q), IC131.14 (D5)
/ch3: IC59.9 (4Q), IC135.14 (D5)
/ch4: IC59.12 (5Q), IC139.14 (D5)
/ch5: IC59.15 (6Q), IC143.14 (D5)
/ch6: IC59.16 (7Q), IC147.14 (D5)
/ch7: IC59.19 (8Q), IC151.14 (D5)
/cl0: IC58.2 (1Q), IC123.15 (D4)
/cl1: IC58.5 (2Q), IC127.15 (D4)
/cl2: IC58.6 (3Q), IC131.15 (D4)
/cl3: IC58.9 (4Q), IC135.15 (D4)
/cl4: IC58.12 (5Q), IC139.15 (D4)
/cl5: IC58.15 (6Q), IC143.15 (D4)
/cl6: IC58.16 (7Q), IC147.15 (D4)
/cl7: IC58.19 (8Q), IC151.15 (D4)
/clk_crystal: SW5.2, U18.14 (D0), U35.6
/condition: IC37.2 (I1), IC76.4 (1Y)
/dh0: IC61.2 (1Q), IC123.12 (D7)
/dh1: IC61.5 (2Q), IC127.12 (D7)
/dh2: IC61.6 (3Q), IC131.12 (D7)
/dh3: IC61.9 (4Q), IC135.12 (D7)
/dh4: IC61.12 (5Q), IC139.12 (D7)
/dh5: IC61.15 (6Q), IC143.12 (D7)
/dh6: IC61.16 (7Q), IC147.12 (D7)
/dh7: IC61.19 (8Q), IC151.12 (D7)
/dih0: IC71.2 (1Q), IC124.12 (D7)
/dih1: IC71.5 (2Q), IC128.12 (D7)
/dih2: IC71.6 (3Q), IC132.12 (D7)
/dih3: IC71.9 (4Q), IC136.12 (D7)
/dih4: IC71.12 (5Q), IC140.12 (D7)
/dih5: IC71.15 (6Q), IC144.12 (D7)
/dih6: IC71.16 (7Q), IC148.12 (D7)
/dih7: IC71.19 (8Q), IC152.12 (D7)
/dil0: IC70.2 (1Q), IC124.13 (D6)
/dil1: IC70.5 (2Q), IC128.13 (D6)
/dil2: IC70.6 (3Q), IC132.13 (D6)
/dil3: IC70.9 (4Q), IC136.13 (D6)
/dil4: IC70.12 (5Q), IC140.13 (D6)
/dil5: IC70.15 (6Q), IC144.13 (D6)
/dil6: IC70.16 (7Q), IC148.13 (D6)
/dil7: IC70.19 (8Q), IC152.13 (D6)
/dl0: IC60.2 (1Q), IC123.13 (D6)
/dl1: IC60.5 (2Q), IC127.13 (D6)
/dl2: IC60.6 (3Q), IC131.13 (D6)
/dl3: IC60.9 (4Q), IC135.13 (D6)
/dl4: IC60.12 (5Q), IC139.13 (D6)
/dl5: IC60.15 (6Q), IC143.13 (D6)
/dl6: IC60.16 (7Q), IC147.13 (D6)
/dl7: IC60.19 (8Q), IC151.13 (D6)
/ext_input: IC50.1 (D3), IC164.9 (Q)
/final_condition: IC21.3 (I), IC37.3 (O)
/flags_4: FLAGS1.12 (Q5), IC5.6 (1C0), IC93.2 (1A)
/flags_5: FLAGS1.15 (Q6), IC5.10 (2C0), IC93.5 (2A)
/flags_6: FLAGS1.16 (Q7), IC6.6 (1C0), IC93.11 (3A)
/flags_7: FLAGS1.19 (Q8), IC6.10 (2C0), IC93.14 (4A)
/flags_cf: FLAGS1.5 (Q2), IC3.10 (2C0), IC14.5 (1C1), IC28.2 (D2), IC30.5 (2A), IC88.4 (D0)
/flags_of: FLAGS1.9 (Q4), IC4.10 (2C0), IC30.14 (4A), IC90.4 (D0)
/flags_sf: FLAGS1.6 (Q3), IC4.6 (1C0), IC30.11 (3A), IC89.6 (1C0)
/flags_zf: FLAGS1.2 (Q1), IC3.6 (1C0), IC30.2 (1A), IC75.5 (I2), IC87.6 (1C0)
/ide: IC116.10 (Y5)
/int_pending: IC29.2 (I1), IC35.3 (O), IC50.2 (D2)
/int_request: IC35.1 (I0), IRQ_ENCODER1.15 (EO)
/int_status_0: IC46.2 (I1), IC126.15 (D4), IRQ_STATUS_1.2 (Q1); also elsewhere on the board
/int_status_1: IC46.5 (I1), IC130.15 (D4), IRQ_STATUS_1.5 (Q2); also elsewhere on the board
/int_status_2: IC46.10 (I1), IC134.15 (D4), IRQ_STATUS_1.6 (Q3); also elsewhere on the board
/int_status_3: IC46.13 (I1), IC138.15 (D4), IRQ_STATUS_1.9 (Q4); also elsewhere on the board
/int_status_4: IC52.2 (I1), IC142.15 (D4), IRQ_STATUS_1.12 (Q5); also elsewhere on the board
/int_status_5: IC52.5 (I1), IC146.15 (D4), IRQ_STATUS_1.15 (Q6); also elsewhere on the board
/int_status_6: IC52.10 (I1), IC150.15 (D4), IRQ_STATUS_1.16 (Q7); also elsewhere on the board
/int_status_7: IC52.13 (I1), IC154.15 (D4), IRQ_STATUS_1.19 (Q8); also elsewhere on the board
/ir0: IC42.2 (1Q), IC80.5 (1C1)
/ir1: IC42.5 (2Q), IC80.11 (2C1)
/ir2: IC42.6 (3Q), IC81.5 (1C1)
/ir3: IC42.9 (4Q), IC81.11 (2C1)
/ir4: IC42.12 (5Q), IC82.5 (1C1)
/ir5: IC42.15 (6Q), IC82.11 (2C1)
/ir6: IC42.16 (7Q), IC83.5 (1C1)
/ir7: IC42.19 (8Q), IC83.11 (2C1)
/irq_masks0: IC46.1 (I0), IC74.2 (1Q), IC126.1 (D3); also elsewhere on the board
/irq_masks1: IC46.4 (I0), IC74.5 (2Q), IC130.1 (D3); also elsewhere on the board
/irq_masks2: IC46.9 (I0), IC74.6 (3Q), IC134.1 (D3); also elsewhere on the board
/irq_masks3: IC46.12 (I0), IC74.9 (4Q), IC138.1 (D3); also elsewhere on the board
/irq_masks4: IC52.1 (I0), IC74.12 (5Q), IC142.1 (D3); also elsewhere on the board
/irq_masks5: IC52.4 (I0), IC74.15 (6Q), IC146.1 (D3); also elsewhere on the board
/irq_masks6: IC52.9 (I0), IC74.16 (7Q), IC150.1 (D3); also elsewhere on the board
/irq_masks7: IC52.12 (I0), IC74.19 (8Q), IC154.1 (D3); also elsewhere on the board
/irq_vector_0: IC126.2 (D2), IRQ_CODE1.2 (1Q)
/irq_vector_1: IC130.2 (D2), IRQ_CODE1.5 (2Q), IRQ_RST_DECODER1.1 (A)
/irq_vector_2: IC134.2 (D2), IRQ_CODE1.6 (3Q), IRQ_RST_DECODER1.2 (B)
/irq_vector_3: IC138.2 (D2), IRQ_CODE1.9 (4Q), IRQ_RST_DECODER1.3 (C)
/irq_vector_4: IC142.2 (D2), IRQ_CODE1.12 (5Q)
/irq_vector_5: IC146.2 (D2), IRQ_CODE1.15 (6Q)
/irq_vector_6: IC150.2 (D2), IRQ_CODE1.16 (7Q)
/irq_vector_7: IC154.2 (D2), IRQ_CODE1.19 (8Q)
/kbus0: IC7.7 (1Y), IC15.3 (1B)
/kbus1: IC7.9 (2Y), IC15.6 (2B)
/kbus2: IC8.7 (1Y), IC15.10 (3B)
/kbus3: IC8.9 (2Y), IC15.13 (4B)
/kbus4: IC9.7 (1Y), IC16.3 (1B)
/kbus5: IC9.9 (2Y), IC16.6 (2B)
/kbus6: IC10.7 (1Y), IC16.10 (3B)
/kbus7: IC10.9 (2Y), IC16.13 (4B)
/ksph0: IC85.2 (1Q), IC126.3 (D1)
/ksph1: IC85.5 (2Q), IC130.3 (D1)
/ksph2: IC85.6 (3Q), IC134.3 (D1)
/ksph3: IC85.9 (4Q), IC138.3 (D1)
/ksph4: IC85.12 (5Q), IC142.3 (D1)
/ksph5: IC85.15 (6Q), IC146.3 (D1)
/ksph6: IC85.16 (7Q), IC150.3 (D1)
/ksph7: IC85.19 (8Q), IC154.3 (D1)
/kspl0: IC84.2 (1Q), IC126.4 (D0)
/kspl1: IC84.5 (2Q), IC130.4 (D0)
/kspl2: IC84.6 (3Q), IC134.4 (D0)
/kspl3: IC84.9 (4Q), IC138.4 (D0)
/kspl4: IC84.12 (5Q), IC142.4 (D0)
/kspl5: IC84.15 (6Q), IC146.4 (D0)
/kspl6: IC84.16 (7Q), IC150.4 (D0)
/kspl7: IC84.19 (8Q), IC154.4 (D0)
/marh_0: IC118.2 (A1), IC125.1 (D3), MARH1.2 (1Q)
/marh_1: IC118.4 (A2), IC129.1 (D3), MARH1.5 (2Q)
/marh_2: IC118.6 (A3), IC133.1 (D3), MARH1.6 (3Q)
/marh_3: IC137.1 (D3), IC157.2 (1A), IC177.10 (A0), IC178.10 (A0), MARH1.9 (4Q)
/marh_4: IC141.1 (D3), IC157.5 (2A), IC177.9 (A1), IC178.9 (A1), MARH1.12 (5Q)
/marh_5: IC145.1 (D3), IC157.11 (3A), IC177.8 (A2), IC178.8 (A2), MARH1.15 (6Q)
/marh_6: IC149.1 (D3), IC157.14 (4A), IC177.7 (A3), IC178.7 (A3), MARH1.16 (7Q)
/marh_7: IC153.1 (D3), IC158.2 (1A), IC177.6 (A4), IC178.6 (A4), MARH1.19 (8Q)
/marl_0: IC117.2 (A1), IC125.2 (D2), MARL1.2 (1Q)
/marl_1: IC117.4 (A2), IC129.2 (D2), MARL1.5 (2Q)
/marl_2: IC117.6 (A3), IC133.2 (D2), MARL1.6 (3Q)
/marl_3: IC117.8 (A4), IC137.2 (D2), MARL1.9 (4Q)
/marl_4: IC117.11 (A1), IC141.2 (D2), MARL1.12 (5Q)
/marl_5: IC117.13 (A2), IC145.2 (D2), MARL1.15 (6Q)
/marl_6: IC117.15 (A3), IC149.2 (D2), MARL1.16 (7Q)
/marl_7: IC117.17 (A4), IC153.2 (D2), MARL1.19 (8Q)
/mdrh_0: IC7.5 (1C1), IC125.14 (D5), IC180.2 (A1), MDRH1.2 (1Q), MDR_OUT_MUX_1.3 (1B)
/mdrh_1: IC7.11 (2C1), IC129.14 (D5), IC180.4 (A2), MDRH1.5 (2Q), MDR_OUT_MUX_1.6 (2B)
/mdrh_2: IC8.5 (1C1), IC133.14 (D5), IC180.6 (A3), MDRH1.6 (3Q), MDR_OUT_MUX_1.10 (3B)
/mdrh_3: IC8.11 (2C1), IC137.14 (D5), IC180.8 (A4), MDRH1.9 (4Q), MDR_OUT_MUX_1.13 (4B)
/mdrh_4: IC9.5 (1C1), IC141.14 (D5), IC180.11 (A1), MDRH1.12 (5Q), MDR_OUT_MUX_2.3 (1B)
/mdrh_5: IC9.11 (2C1), IC145.14 (D5), IC180.13 (A2), MDRH1.15 (6Q), MDR_OUT_MUX_2.6 (2B)
/mdrh_6: IC10.5 (1C1), IC149.14 (D5), IC180.15 (A3), MDRH1.16 (7Q), MDR_OUT_MUX_2.10 (3B)
/mdrh_7: IC10.11 (2C1), IC153.14 (D5), IC180.17 (A4), MDRH1.19 (8Q), MDR_OUT_MUX_2.13 (4B)
/mdrl_0: IC7.6 (1C0), IC125.15 (D4), IC179.2 (A1), MDRL1.2 (1Q), MDR_OUT_MUX_1.2 (1A)
/mdrl_1: IC7.10 (2C0), IC129.15 (D4), IC179.4 (A2), MDRL1.5 (2Q), MDR_OUT_MUX_1.5 (2A)
/mdrl_2: IC8.6 (1C0), IC133.15 (D4), IC179.6 (A3), MDRL1.6 (3Q), MDR_OUT_MUX_1.11 (3A)
/mdrl_3: IC8.10 (2C0), IC137.15 (D4), IC179.8 (A4), MDRL1.9 (4Q), MDR_OUT_MUX_1.14 (4A)
/mdrl_4: IC9.6 (1C0), IC141.15 (D4), IC179.11 (A1), MDRL1.12 (5Q), MDR_OUT_MUX_2.2 (1A)
/mdrl_5: IC9.10 (2C0), IC145.15 (D4), IC179.13 (A2), MDRL1.15 (6Q), MDR_OUT_MUX_2.5 (2A)
/mdrl_6: IC10.6 (1C0), IC149.15 (D4), IC179.15 (A3), MDRL1.16 (7Q), MDR_OUT_MUX_2.11 (3A)
/mdrl_7: IC10.10 (2C0), IC153.15 (D4), IC179.17 (A4), MDRL1.19 (8Q), MDR_OUT_MUX_2.14 (4A)
/mem_select_0: IC176.15 (Y0), U7.22 (CE)
/mem_select_1: IC176.14 (Y1), U6.22 (CE)
/mem_select_2: IC176.13 (Y2), U5.22 (CE)
/mem_select_3: IC176.12 (Y3), U4.22 (CE)
/mem_select_4: IC176.11 (Y4), U8.22 (CE)
/mem_select_5: IC176.10 (Y5), U3.22 (CE)
/mem_select_6: IC176.9 (Y6), U2.22 (CE)
/mem_select_7: IC176.7 (Y7), U1.22 (CE)
/mux_a: IC13.11 (O), IC77.14 (A), IC78.14 (A), IC79.14 (A), IC80.14 (A), IC81.14 (A), IC82.14 (A), IC83.14 (A)
/mux_b: IC13.6 (O), IC77.2 (B), IC78.2 (B), IC79.2 (B), IC80.2 (B), IC81.2 (B), IC82.2 (B), IC83.2 (B)
/page_table_addr_source: IC29.8 (O), IC190.1 (~A/B), IC191.1 (~A/B)
/panel_address_0: IC198.2 (A1), RN4.1 (R1.1), SW7.8
/panel_address_1: IC198.4 (A2), RN4.2 (R2.1), SW7.7
/panel_address_2: IC198.6 (A3), RN4.3 (R3.1), SW7.6
/panel_address_3: IC198.8 (A4), RN4.4 (R4.1), SW7.5
/panel_address_4: IC198.11 (A1), RN4.5 (R5.1), SW7.4
/panel_address_5: IC198.13 (A2), RN4.6 (R6.1), SW7.3
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

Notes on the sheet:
marh
halt: use the halt flag to tri-state all buses. do microcode loop to test for interrupts or dma. if no interrupts or dma then just perform tight loop of zero offset. when int or dma appears, jump +1. next microinstr is pre-fetch type, so that int or dma can be executed. pc will be pointing to after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
this comes from the microcode board but is not a control bit. it is a combination of two bits.
bph
rewiring the a1/a27 of the roms will be difficult and could damage the wiring and destroy the board.
IMPROVE THIS PART OF THE CIRCUIT
alu_op == add
mdr mux
adder
removed trace_mode flag from here. (no longer exists)
low
marl
microcode 0 to 63 is reserved for cpu startup. fetch at 0x10 trap at 0x20
if type = branch, and condition = false, then next = +1
carry in mux
this is the positive edge version of the master reset signal
int_pending input to conditional is to be used with halt instruction to check if ints are pending. it is also used with the cpu trace mode so that when coming out of the trace microcode loop, we can jump to the interrupts handler if interrupts are pending. without the int_pending conditional it is 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
single step clock
HEAD LOAD (Option for double-sided version only) This signal line is used either HEAD LOAD or IN USE. When this signal is low, R/W head loads against the diskette. The set-up time of the solenoid is recuired before using this signal. This signal line responds to the input signal regardless of DRIVE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
unused signals
status
microcode sequencing
to calculate of when doing shifts we first save the sign of the original number, then when done shifting we save the value of the result. then we do a xor of both values, and the result is the of. the result of the xor is the msb of the result (zbus7). this is why wehave zbus7 as one of the inputs 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
ptb
front panel register display
512kb ram modules. 8 modules giving a total of 4mb
244 microcode signals need inverter because they get reset to zero at beginning, and 244 are low active. this causes problems on reset.
add mux here to create esc opcode
shl: msb goes into cf. lsb replaced by 0 sla: same as shl rol: lsb becomes msb. rlc: msb goes into cf. lsb becomes cf shr: lsb goes into cf. msb replaced by 0 sra: lsb goes into cf. msb is whatever the previous one was ror: msb becomes lsb rrc: msb becomes cf. lsb goes into cf
pcl
74HCT244 is used here because it recognizes TTL input levels. ttl levels are lower than CMOS, and the esp works at 3.3V. so when a high level is generated by the esp, it will go thru the HCT and it will trconize it as a high, whereas a niejjA
lt lte ~lt = gte ~lte + gt
g_h
0 = kernel 1 = user
unused
u_flags
sih
irq masks
alu_mode removed. of is undefined if alu in logic mode anyway.
ssph

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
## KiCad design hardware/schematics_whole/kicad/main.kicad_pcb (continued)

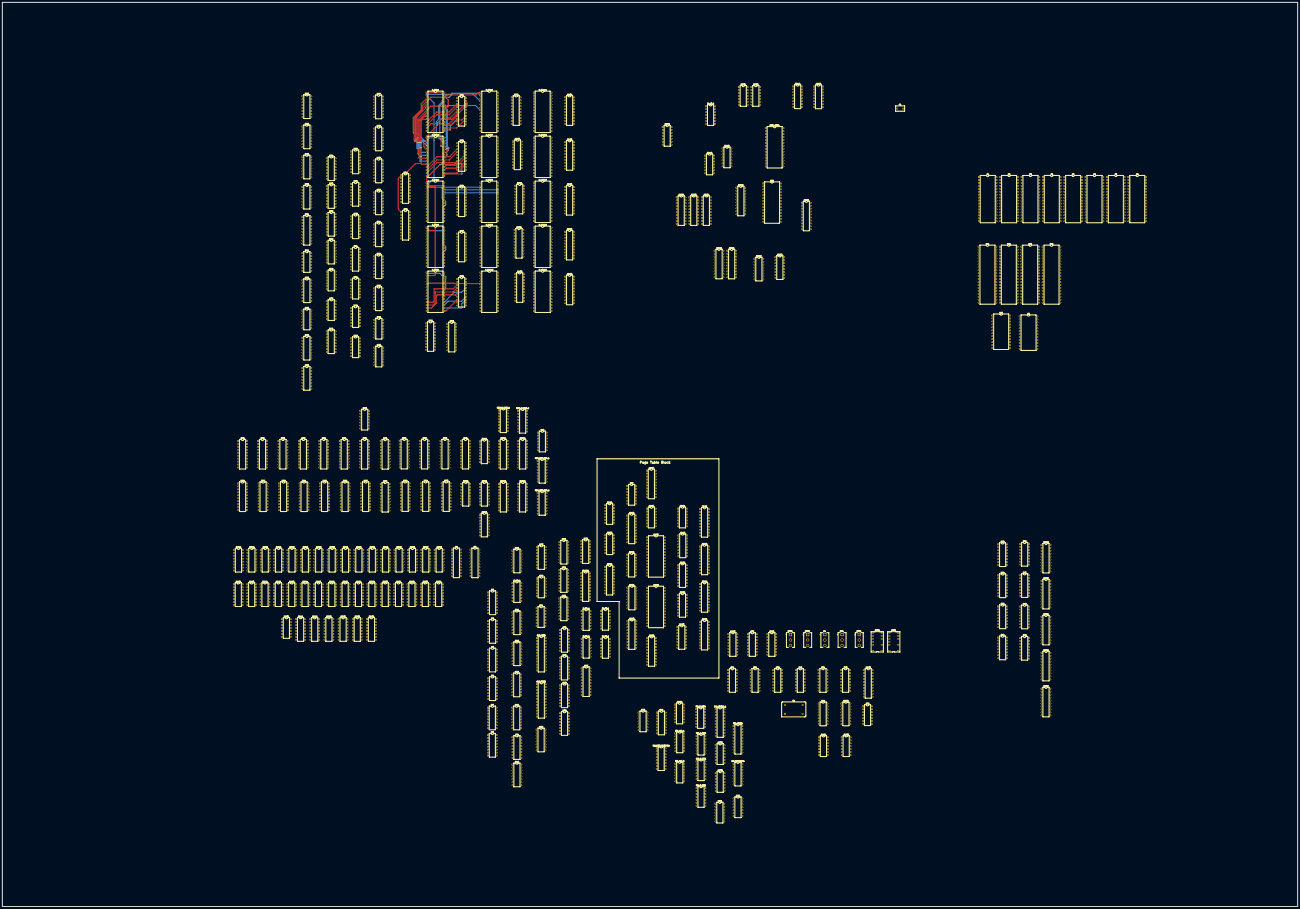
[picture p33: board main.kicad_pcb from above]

Board: 2 copper layers, 1116.0 x 779.0 mm, 288 parts (0 on the bottom side), 1031 nets.

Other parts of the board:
IC207, IC208: 7400N; DIP-14_W7.62mm

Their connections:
/int_status_0: IC207.2 (I1); also elsewhere on the board
/int_status_1: IC207.5 (I1); also elsewhere on the board
/int_status_2: IC207.10 (I1); also elsewhere on the board
/int_status_3: IC207.13 (I1); also elsewhere on the board
/int_status_4: IC208.2 (I1); also elsewhere on the board
/int_status_5: IC208.5 (I1); also elsewhere on the board
/int_status_6: IC208.10 (I1); also elsewhere on the board
/int_status_7: IC208.13 (I1); also elsewhere on the board
/irq_masks0: IC207.1 (I0); also elsewhere on the board
/irq_masks1: IC207.4 (I0); also elsewhere on the board
/irq_masks2: IC207.9 (I0); also elsewhere on the board
/irq_masks3: IC207.12 (I0); also elsewhere on the board
/irq_masks4: IC208.1 (I0); also elsewhere on the board
/irq_masks5: IC208.4 (I0); also elsewhere on the board
/irq_masks6: IC208.9 (I0); also elsewhere on the board
/irq_masks7: IC208.12 (I0); also elsewhere on the board

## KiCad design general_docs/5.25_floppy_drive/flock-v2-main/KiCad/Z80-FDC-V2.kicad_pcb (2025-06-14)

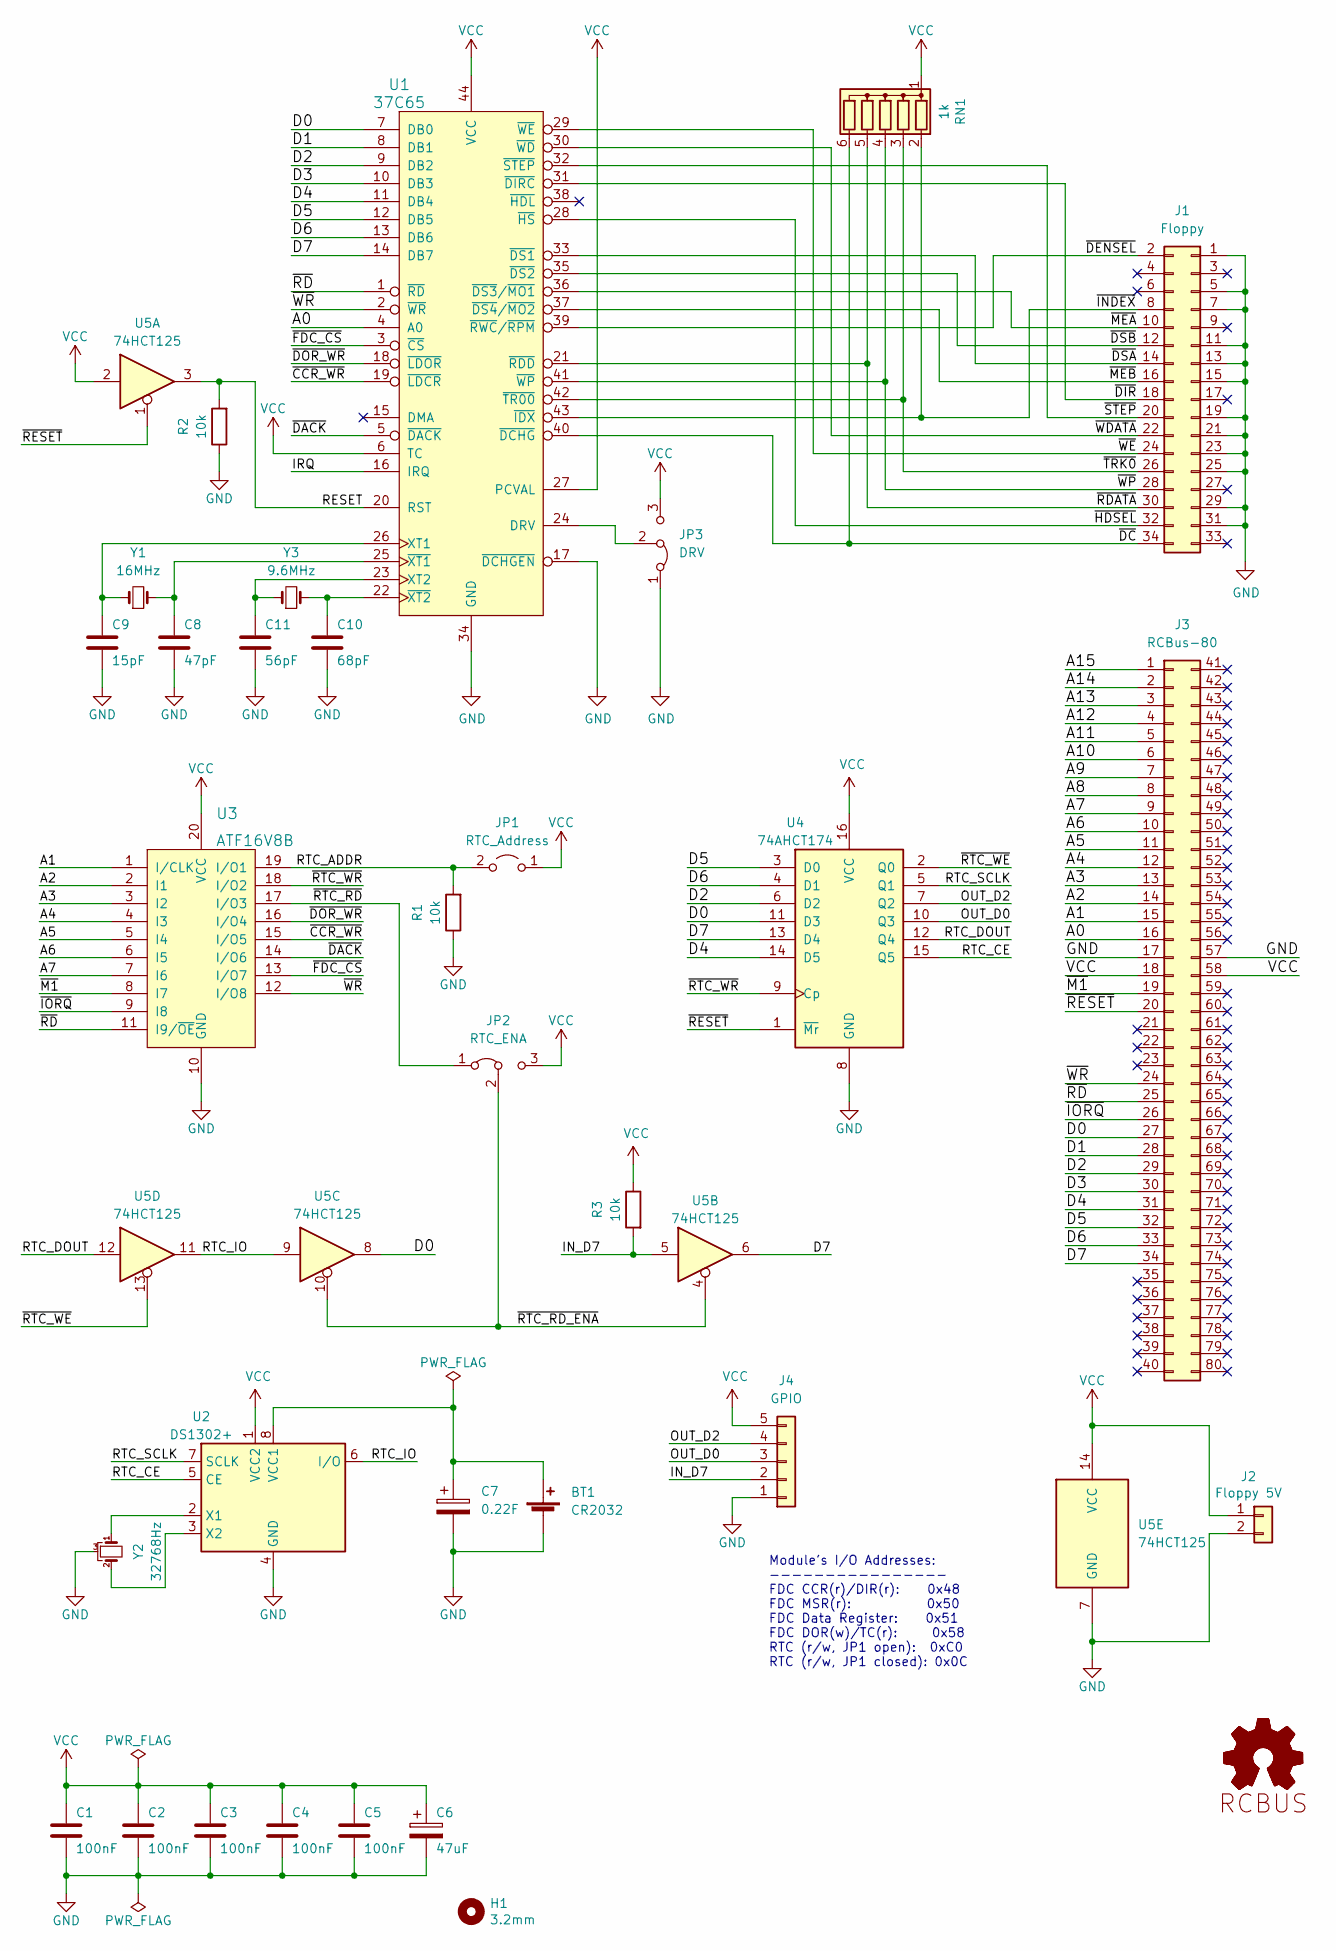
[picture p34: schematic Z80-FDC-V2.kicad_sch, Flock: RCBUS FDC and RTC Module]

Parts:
BT1: CR2032; Battery_Holder_CR2032_Universal
C1, C2, C3, C4, C5: 100nF; Cap_Cer_508
C6: 47uF; Cap_Elec_Radial_6.3mm
C7: 0.22F; Cap_Super_Radial_13.5mm
C8: 47pF; Cap_Cer_508
C9: 15pF; Cap_Cer_508
C10: 68pF; Cap_Cer_508
C11: 56pF; Cap_Cer_508
H1: 3.2mm; MountingHole_3.2mm_M3_DIN965
J1: Floppy; Conn_Pin_Header_17x2_2.54mm_Shrouded_RA
J2: Floppy 5V; Conn_TE_2-644488-2_2P_2.54mm
J3: RCBus-80; Conn_Pin_Header_40x2_2.54mm_Right_Angle_RCBus80
J4: GPIO; Conn_Pin_Header_5x1_2.54mm
JP1: RTC_Address; Conn_Pin_Header_2x1_2.54mm_NoKey
JP2: RTC_ENA; SolderJumper-3_P1.3mm_Bridged12_RoundedPad1.0x1.5mm_NumberL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
JP3: DRV; SolderJumper-3_P1.3mm_Bridged12_RoundedPad1.0x1.5mm_NumberL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
LOGO1, LOGO2: Logo_Open_Hardware_Small; OSHW-Logo_5.7x6mm_SilkScreen
LOGO3: RCBUS_Logo
R1, R2, R3: 10k; Res_762
RN1: 1k; Conn_SIL6
U1: 37C65; IC_PLCC44_TH
U2: DS1302+; IC_DIP8_300
U3: ATF16V8B; IC_DIP20_300
U4: 74AHCT174; IC_DIP16_300
U5: 74HCT125; IC_DIP14_300
Y1: 16MHz; Crystal_HC-49U_Vert
Y2: 32768Hz; Crystal_32K_Horiz
Y3: 9.6MHz; Crystal_HC-49U_Vert

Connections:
/A0: J3.16, U1.4 (A0)
/A1: J3.15, U3.1 (I/CLK)
/A2: J3.14, U3.2 (I1)
/A3: J3.13, U3.3 (I2)
/A4: J3.12, U3.4 (I3)
/A5: J3.11, U3.5 (I4)
/A6: J3.10, U3.6 (I5)
/A7: J3.9, U3.7 (I6)
/A8: J3.8
/A9: J3.7
/A10: J3.6
/A11: J3.5
/A12: J3.4
/A13: J3.3
/A14: J3.2
/A15: J3.1
/D0: J3.27, U1.7 (DB0), U4.11 (D3), U5.8
/D1: J3.28, U1.8 (DB1)
/D2: J3.29, U1.9 (DB2), U4.6 (D2)
/D3: J3.30, U1.10 (DB3)
/D4: J3.31, U1.11 (DB4), U4.14 (D5)
/D5: J3.32, U1.12 (DB5), U4.3 (D0)
/D6: J3.33, U1.13 (DB6), U4.4 (D1)
/D7: J3.34, U1.14 (DB7), U4.13 (D4), U5.6
/IN_D7: J4.2, R3.2, U5.5
/IRQ: U1.16 (IRQ)
/OUT_D0: J4.3, U4.10 (Q3)
/OUT_D2: J4.4, U4.7 (Q2)
/RESET: R2.2, U1.20 (RST), U5.3
/RTC_ADDR: JP1.2 (B), R1.2, U3.19 (I/O1)
/RTC_CE: U2.5 (CE), U4.15 (Q5)
/RTC_DOUT: U4.12 (Q4), U5.12
/RTC_IO: U2.6 (I/O), U5.9, U5.11
/RTC_SCLK: U2.7 (SCLK), U4.5 (Q1)
/~CCR_WR: U1.19 (~LDCR), U3.15 (I/O5)
/~DACK: U1.5 (~DACK), U3.14 (I/O6)
/~DC: J1.34, RN1.6 (R5), U1.40 (~DCHG)
/~DENSEL: J1.2, U1.39 (~RWC/~RPM)
/~DIR: J1.18, U1.31 (~DIRC)
/~DOR_WR: U1.18 (~LDOR), U3.16 (I/O4)
/~DSA: J1.14, U1.33 (~DS1)
/~DSB: J1.12, U1.35 (~DS2)
/~FDC_CS: U1.3 (~CS), U3.13 (I/O7)
/~HDSEL: J1.32, U1.28 (~HS)
/~INDEX: J1.8, RN1.2 (R1), U1.43 (~IDX)
/~IORQ: J3.26, U3.9 (I8)
/~M1: J3.19, U3.8 (I7)
/~MEA: J1.10, U1.36 (~DS3/~MO1)
/~MEB: J1.16, U1.37 (~DS4/~MO2)
/~RDATA: J1.30, RN1.5 (R4), U1.21 (~RDD)
/~RD: J3.25, U1.1 (~RD), U3.11 (I9/~OE)
/~RESET: J3.20, U4.1 (~Mr), U5.1
/~RFSH: J3.59
/~RTC_RD_ENA: JP2.2 (C), U5.4, U5.10
/~RTC_RD: JP2.1 (A), U3.17 (I/O3)
/~RTC_WE: U4.2 (Q0), U5.13
/~RTC_WR: U3.18 (I/O2), U4.9 (Cp)
/~STEP: J1.20, U1.32 (~STEP)
/~TRK0: J1.26, RN1.3 (R2), U1.42 (~TR00)
/~WDATA: J1.22, U1.30 (~WD)
/~WE: J1.24, U1.29 (~WE)
/~WP: J1.28, RN1.4 (R3), U1.41 (~WP)
/~WR: J3.24, U1.2 (~WR), U3.12 (I/O8)
GND: BT1.2 (-), C1.2, C2.2, C3.1, C4.2, C5.2, C6.2, C7.2, C8.2, C9.2, C10.2, C11.2, J1.1, J1.5, J1.7, J1.11, J1.13, J1.15, J1.19, J1.21, J1.23, J1.25, J1.29, J1.31, J2.2, J3.17, J3.57, J4.1, JP3.1 (A), R1.1, R2.1, U1.17 (~DCHGEN), U1.34 (GND), U2.4 (GND), U3.10 (GND), U4.8 (GND), U5.7 (GND), Y2.3
unnamed: BT1.1 (+), C7.1, U2.8 (VCC1)
unnamed: C8.1, U1.25 (~XT1), Y1.2
unnamed: C9.1, U1.26 (XT1), Y1.1
unnamed: C10.1, U1.22 (~XT2), Y3.2
unnamed: C11.1, U1.23 (XT2), Y3.1
unnamed: JP3.2 (C), U1.24 (DRV)
unnamed: U2.2 (X1), Y2.1
unnamed: U2.3 (X2), Y2.2
VCC: C1.1, C2.1, C3.2, C4.1, C5.1, C6.1, J2.1, J3.18, J3.58, J4.5, JP1.1 (A), JP2.3 (B), JP3.3 (B), R3.1, RN1.1 (common), U1.6 (TC), U1.27 (PCVAL), U1.44 (VCC), U2.1 (VCC2), U3.20 (VCC), U4.16 (VCC), U5.2, U5.14 (VCC)

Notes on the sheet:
Module's I/O Addresses: ---------------- FDC CCR(r)/DIR(r): 0x48 FDC MSR(r): 0x50 FDC Data Register: 0x51 FDC DOR(w)/TC(r): 0x58 RTC (r/w, JP1 open): 0xC0 RTC (r/w, JP1 closed): 0x0C

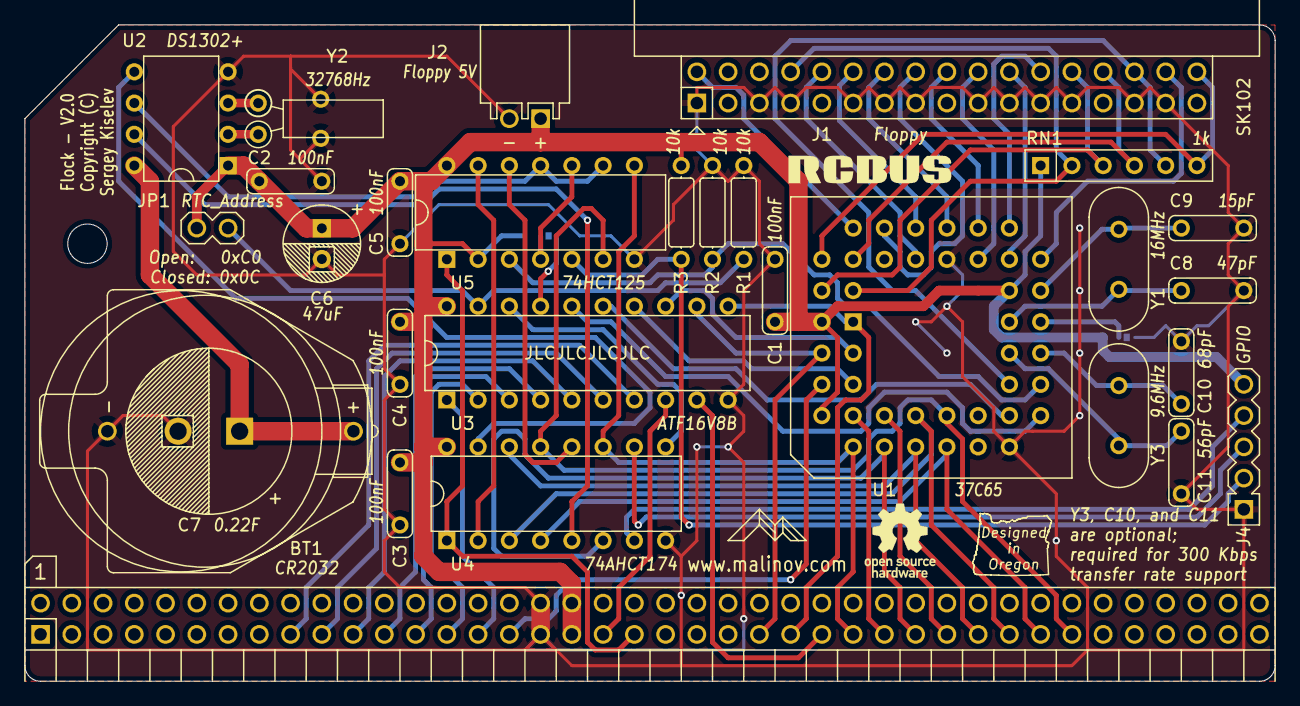
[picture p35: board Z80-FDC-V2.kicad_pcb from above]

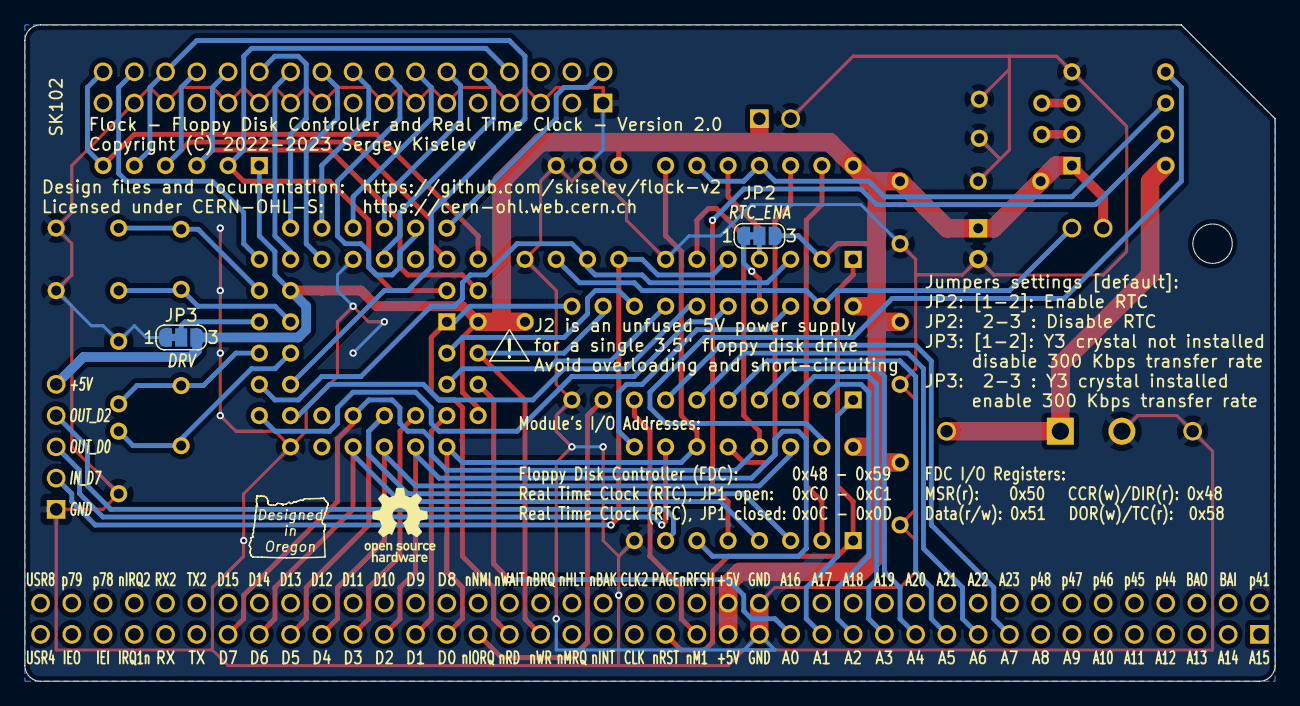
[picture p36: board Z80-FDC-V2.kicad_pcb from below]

Board: 2 copper layers, 101.6 x 53.3 mm, 35 parts (3 on the bottom side), 63 nets.

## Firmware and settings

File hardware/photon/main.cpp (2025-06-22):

//---------------------------------------------------------------------------

#include <ctype.h>
#include <stdio.h>
#include <stdlib.h>
#include <vcl.h>
#include <math.h>
#include <windows.h>
#include <IniFiles.hpp>

#include <cctype>


#include <algorithm>
#pragma hdrstop

#include "main.h"





//---------------------------------------------------------------------------
#pragma package(smart_init)
#pragma link "CGAUGES"
#pragma link "trayicon"
#pragma link "CGRID"
#pragma link "PERFGRAP"
#pragma link "SHDocVw_OCX"
#pragma resource "*.dfm"
Tfmain *fmain;


#define ID_LEN 64
#define NBR_ROMS 15
#define TOTAL_CONTROL_BITS NBR_ROMS * 8
#define CYCLES_PER_INSTR 64
#define NBR_INSTRUCTIONS 256
#define TOTAL_CYCLES CYCLES_PER_INSTR * NBR_INSTRUCTIONS
#define STRING_LEN 256
#define INFO_LEN 256

#define PROMPT_LEN 128 * 1024

void send_msg(String s);
void do_copy(void);
void do_paste(void);
void do_reset(void);
void shift(int amount);
void get_token(void);
int POW(int n, int e);
void update_display(void);
void reset_lists(int cycle);
void NEW(void);
void write_cycle(void);
char *intToBinStr(char *str, unsigned char n);
String hexstr_char(unsigned char i);


unsigned int cycle_nbr = 0;
unsigned int instr_nbr = 0;
unsigned int ROM_nbr = 0;
char instr_name_clip[STRING_LEN];
char info[NBR_INSTRUCTIONS * CYCLES_PER_INSTR][INFO_LEN];
char info_clip[NBR_INSTRUCTIONS * CYCLES_PER_INSTR][INFO_LEN];
char instr_names[NBR_INSTRUCTIONS][STRING_LEN];
char instr_names_clip[NBR_INSTRUCTIONS][STRING_LEN];
unsigned char clipboard[NBR_INSTRUCTIONS * CYCLES_PER_INSTR][NBR_ROMS];
unsigned char ROMS[NBR_ROMS][NBR_INSTRUCTIONS * CYCLES_PER_INSTR];
unsigned char booltoint(bool b);
unsigned int get_index(String name);

int from_origin, from_dest;
int key_count;
char filename[STRING_LEN];
int from1, from2, to1, to2;

int textarea_len = 1;

bool read_only = true;

int focus_index;

String textarea_data;



__fastcall Tfmain::Tfmain(TComponent* Owner)
	: TForm(Owner)
{
}


unsigned int get_index(String name){
        return fmain->control_list->Items->IndexOf(name);

}



String hexstr_char(unsigned char i){
        String s;
        char table[] = "0123456789ABCDEF";

        s = s + table[(i & 0xF0) >> 4] + table[i & 0x0F];

        return s;

}


String hexstr(unsigned int i){
        String s;
        unsigned int a1, a2;

        a1 = (i / 16);
        switch(a1){
                case 10:
                        s = s + "A";
                        break;
                case 11:
                        s = s + "B";
                        break;
                case 12:
                        s = s + "C";
                        break;
                case 13:
                        s = s + "D";
                        break;
                case 14:
                        s = s + "E";
                        break;
                case 15:
                        s = s + "F";
                        break;
                default:
                        s = s + IntToStr(a1);
        }                                


        a2 = i % 16;
        switch(a2){
                case 10:
                        s = s + "A";
                        break;
                case 11:
                        s = s + "B";
                        break;
                case 12:
                        s = s + "C";
                        break;
                case 13:
                        s = s + "D";
                        break;
                case 14:
                        s = s + "E";
                        break;
                case 15:
                        s = s + "F";
                        break;
                default:
                        s = s + IntToStr(a2);
        }

        return s;

}
              



void READ(void){
        FILE *fp;
        TIniFile *ini;
        char name[STRING_LEN];
        char fullname[STRING_LEN];
        int pos;

        int val;
        int i, j, k;

        if(fmain->OpenDialog1->Execute()){

                strcpy(filename, fmain->OpenDialog1->FileName.c_str());
                ini = new TIniFile("config.ini");
                ini->WriteString("general", "last_microcode_open", filename);
                delete ini;
                fmain->Caption = filename;
                strcpy(fullname, ExtractFileName(fmain->OpenDialog1->FileName).c_str());

                strcpy(name, fullname);
                fp = fopen(name, "r+b");
                fread(info, sizeof(char), NBR_INSTRUCTIONS * CYCLES_PER_INSTR * INFO_LEN, fp);
                fread(instr_names, sizeof(char), NBR_INSTRUCTIONS * STRING_LEN, fp);
                fclose(fp);

                for(i = 0; i < 15; i++){
                        strcpy(name, fullname);
                        strcat(name, IntToStr(i).c_str());
                        fp = fopen(name, "r+b");
                        fread(&ROMS[i], sizeof(unsigned char), NBR_INSTRUCTIONS * CYCLES_PER_INSTR, fp);
                        fclose(fp);

                }

                for(i = 0; i < 256; i++){
                        fmain->list_names->Items->Add("0x" + hexstr(i) + ": " + instr_names[i]);

                }
        }

}









void WRITE(void){
        FILE *fp;

        char name[STRING_LEN];
        char fullname[STRING_LEN];
        int pos;

        int val;
        int i, j, k;

        if(fmain->SaveDialog2->Execute())
        {
                strcpy(filename, fmain->SaveDialog2->FileName.c_str());
                fmain->Caption = filename;

                strcpy(fullname, ExtractFileName(fmain->SaveDialog2->FileName).c_str());
                strcpy(name, fullname);
                fp = fopen(name, "w+b");
                fwrite(info, sizeof(char), NBR_INSTRUCTIONS * CYCLES_PER_INSTR * STRING_LEN, fp);
                fwrite(instr_names, sizeof(char), NBR_INSTRUCTIONS * STRING_LEN, fp);
                fclose(fp);

                for(i = 0; i < 15; i++){
                        strcpy(name, fullname);
                        strcat(name, IntToStr(i).c_str());
                        fp = fopen(name, "w+b");
                        fwrite(&ROMS[i], sizeof(unsigned char), NBR_INSTRUCTIONS * CYCLES_PER_INSTR, fp);
                        fclose(fp);

                }
        }



}

void reset_lists(int cycle){
        strcpy(info[cycle], "");
        ROMS[0][cycle] = 0;
        ROMS[1][cycle] = 0;
        ROMS[2][cycle] = 0xC0;
        ROMS[3][cycle] = 0;
        ROMS[4][cycle] = 0;
        ROMS[5][cycle] = 0;
        ROMS[6][cycle] = 0;
        ROMS[7][cycle] = 0xF0;
        ROMS[8][cycle] = 0x8F;
        ROMS[9][cycle] = 0xFF;
        ROMS[10][cycle] = 0xFF;
        ROMS[11][cycle] = 0x47;
        ROMS[12][cycle] = 0xC0;
        ROMS[13][cycle] = 0;
        ROMS[14][cycle] = 0;

}

int POW(int n, int e){

        if(e == 0) return 1;
        else return n * POW(n, e - 1);

}

void Tfmain::write_cycle(void){
        int val;
        int i, j, k;
        int rom;

        if(read_only == true) return;

        strcpy(info[cycle_nbr], memo_info->Text.c_str());
        strcpy(instr_names[cycle_nbr / CYCLES_PER_INSTR], memo_name->Text.c_str());

        for(i = 0; i < 15 * 8; i++){
                if(i % 8 == 0) val = 0;
                if(control_list->Checked[i]) val = val + POW(2, i % 8);
                control_list->Checked[i % 8] = false;

                ROMS[i / 8][cycle_nbr] = val;
        }

        update_display();
}



//---------------------------------------------------------------------------

//---------------------------------------------------------------------------




void __fastcall Tfmain::Button34Click(TObject *Sender)
{
         reset_lists(cycle_nbr);
         update_display();
}
//---------------------------------------------------------------------------



//---------------------------------------------------------------------------

unsigned char booltoint(bool b){
        if(b == true) return 1;
        else return 0;
}

void update_display(void){
        int i, j;
        unsigned char index;
        char offset;

        fmain->list_names->Clear();
        for(i = 0; i < 256; i++){
                        fmain->list_names->Items->Add(hexstr(i) + ": " + instr_names[i]);
        }
                
        for(i = 0; i < 15; i++){
                for(j = 0; j < 8; j++){
                        fmain->control_list->Checked[i * 8 + j] = ROMS[i][cycle_nbr] & POW(2, j);
                }
        }

        fmain->memo_info->Text = info[cycle_nbr];
        fmain->memo_name->Text = instr_names[cycle_nbr / CYCLES_PER_INSTR];

        fmain->list_names->Selected[cycle_nbr / CYCLES_PER_INSTR] = true;

        index = booltoint(fmain->control_list->Checked[0]) | (booltoint(fmain->control_list->Checked[1]) << 1);
        fmain->combo_type->ItemIndex = index;

        index = booltoint(fmain->control_list->Checked[fmain->control_list->Items->IndexOf("cond_flags_src")]);
        fmain->combo_flags_src->ItemIndex = index;

        index = booltoint(fmain->control_list->Checked[fmain->control_list->Items->IndexOf("mdr_in_src")]);
        fmain->combo_mdr_src->ItemIndex = index;

        index = booltoint(fmain->control_list->Checked[fmain->control_list->Items->IndexOf("mdr_out_src")]);
        fmain->combo_mdr_src_out->ItemIndex = index;

        index = booltoint(fmain->control_list->Checked[fmain->control_list->Items->IndexOf("mar_in_src")]);
        fmain->combo_mar_src->ItemIndex = index;

        index = booltoint(fmain->control_list->Checked[fmain->control_list->Items->IndexOf("alu_cf_out_inv")]);
        fmain->combo_alu_cf_out_inv->ItemIndex = index;

        index = booltoint(fmain->control_list->Checked[fmain->control_list->Items->IndexOf("alu_cf_in_src_0")])
          | booltoint(fmain->control_list->Checked[fmain->control_list->Items->IndexOf("alu_cf_in_src_1")]) << 1
          |  booltoint(fmain->control_list->Checked[fmain->control_list->Items->IndexOf("alu_cf_in_inv")]) << 2;
        fmain->combo_alu_cf_in->ItemIndex = index;

        index = booltoint(fmain->control_list->Checked[fmain->control_list->Items->IndexOf("shift_src_0")])
          | booltoint(fmain->control_list->Checked[fmain->control_list->Items->IndexOf("shift_src_1")]) << 1
          |  booltoint(fmain->control_list->Checked[fmain->control_list->Items->IndexOf("shift_src_2")]) << 2;
        fmain->combo_shift_src->ItemIndex = index;

        index = booltoint(fmain->control_list->Checked[fmain->control_list->Items->IndexOf("alu_a_src_0")])
          | booltoint(fmain->control_list->Checked[fmain->control_list->Items->IndexOf("alu_a_src_1")]) << 1
          |  booltoint(fmain->control_list->Checked[fmain->control_list->Items->IndexOf("alu_a_src_2")]) << 2
          | booltoint(fmain->control_list->Checked[fmain->control_list->Items->IndexOf("alu_a_src_3")]) << 3
          | booltoint(fmain->control_list->Checked[fmain->control_list->Items->IndexOf("alu_a_src_4")]) << 4
          | booltoint(fmain->control_list->Checked[fmain->control_list->Items->IndexOf("alu_a_src_5")]) << 5;
        fmain->combo_aluAmux->ItemIndex = index;

        index = booltoint(fmain->control_list->Checked[fmain->control_list->Items->IndexOf("alu_a_src_0")])
          | booltoint(fmain->control_list->Checked[fmain->control_list->Items->IndexOf("alu_a_src_1")]) << 1
          |  booltoint(fmain->control_list->Checked[fmain->control_list->Items->IndexOf("alu_a_src_2")]) << 2
          | booltoint(fmain->control_list->Checked[fmain->control_list->Items->IndexOf("alu_a_src_3")]) << 3
          | booltoint(fmain->control_list->Checked[fmain->control_list->Items->IndexOf("alu_a_src_4")]) << 4
          | booltoint(fmain->control_list->Checked[fmain->control_list->Items->IndexOf("alu_a_src_5")]) << 5;
        fmain->combo_aluAmux->ItemIndex = index;

        index = booltoint(fmain->control_list->Checked[fmain->control_list->Items->IndexOf("alu_b_src_0")])
          | booltoint(fmain->control_list->Checked[fmain->control_list->Items->IndexOf("alu_b_src_1")]) << 1
          |  booltoint(fmain->control_list->Checked[fmain->control_list->Items->IndexOf("alu_b_src_2")]) << 2;
        fmain->combo_aluBmux->ItemIndex = index;

        index = booltoint(fmain->control_list->Checked[fmain->control_list->Items->IndexOf("zbus_out_src_0")])
          | booltoint(fmain->control_list->Checked[fmain->control_list->Items->IndexOf("zbus_out_src_1")]) << 1;
        fmain->combo_zbus->ItemIndex = index;

        offset = booltoint(fmain->control_list->Checked[fmain->control_list->Items->IndexOf("offset_0")])
          | booltoint(fmain->control_list->Checked[fmain->control_list->Items->IndexOf("offset_1")]) << 1
          |  booltoint(fmain->control_list->Checked[fmain->control_list->Items->IndexOf("offset_2")]) << 2
          | booltoint(fmain->control_list->Checked[fmain->control_list->Items->IndexOf("offset_3")]) << 3
          | booltoint(fmain->control_list->Checked[fmain->control_list->Items->IndexOf("offset_4")]) << 4
          | booltoint(fmain->control_list->Checked[fmain->control_list->Items->IndexOf("offset_5")]) << 5
          | booltoint(fmain->control_list->Checked[fmain->control_list->Items->IndexOf("offset_6")]) << 6;
        offset = offset | ((offset << 1) & 0x80);
        fmain->edt_integer->Text = IntToStr(offset);


        index = booltoint(fmain->control_list->Checked[fmain->control_list->Items->IndexOf("cond_sel_0")])
          | booltoint(fmain->control_list->Checked[fmain->control_list->Items->IndexOf("cond_sel_1")]) << 1
          |  booltoint(fmain->control_list->Checked[fmain->control_list->Items->IndexOf("cond_sel_2")]) << 2
          | booltoint(fmain->control_list->Checked[fmain->control_list->Items->IndexOf("cond_sel_3")]) << 3
          | booltoint(fmain->control_list->Checked[fmain->control_list->Items->IndexOf("cond_inv")]) << 4;
        fmain->combo_cond->ItemIndex = index;


        index = booltoint(fmain->control_list->Checked[fmain->control_list->Items->IndexOf("zf_in_src_0")])
          | booltoint(fmain->control_list->Checked[fmain->control_list->Items->IndexOf("zf_in_src_1")]) << 1;
        fmain->combo_zf_in->ItemIndex = index;

        index = booltoint(fmain->control_list->Checked[fmain->control_list->Items->IndexOf("cf_in_src_0")])
          | booltoint(fmain->control_list->Checked[fmain->control_list->Items->IndexOf("cf_in_src_1")]) << 1
          |  booltoint(fmain->control_list->Checked[fmain->control_list->Items->IndexOf("cf_in_src_2")]) << 2;
        fmain->combo_cf_in->ItemIndex = index;

        index = booltoint(fmain->control_list->Checked[fmain->control_list->Items->IndexOf("sf_in_src_0")])
          | booltoint(fmain->control_list->Checked[fmain->control_list->Items->IndexOf("sf_in_src_1")]) << 1;
        fmain->combo_sf_in->ItemIndex = index;

        index = booltoint(fmain->control_list->Checked[fmain->control_list->Items->IndexOf("of_in_src_0")])
          | booltoint(fmain->control_list->Checked[fmain->control_list->Items->IndexOf("of_in_src_1")]) << 1
          |  booltoint(fmain->control_list->Checked[fmain->control_list->Items->IndexOf("of_in_src_2")]) << 2;
        fmain->combo_of_in->ItemIndex = index;



        index = booltoint(fmain->control_list->Checked[fmain->control_list->Items->IndexOf("uzf_in_src_0")])
          | booltoint(fmain->control_list->Checked[fmain->control_list->Items->IndexOf("uzf_in_src_1")]) << 1;
        fmain->combo_uzf->ItemIndex = index;

        index = booltoint(fmain->control_list->Checked[fmain->control_list->Items->IndexOf("ucf_in_src_0")])
          | booltoint(fmain->control_list->Checked[fmain->control_list->Items->IndexOf("ucf_in_src_1")]) << 1;
        fmain->combo_ucf->ItemIndex = index;

        index = booltoint(fmain->control_list->Checked[fmain->control_list->Items->IndexOf("usf_in_src")]);
        fmain->combo_usf->ItemIndex = index;

        index = booltoint(fmain->control_list->Checked[fmain->control_list->Items->IndexOf("uof_in_src")]);
        fmain->combo_uof->ItemIndex = index;
}

void NEW(void){
        int i;

        cycle_nbr = 0;
        
        
        for(i = 0; i < NBR_INSTRUCTIONS * CYCLES_PER_INSTR; i++){
                reset_lists(i);
        }
        for(i = 0; i < NBR_INSTRUCTIONS; i++){
                strcpy(instr_names[i], "");
                fmain->list_names->Items->Add("0x" + hexstr(i) + ": ");
        }
                                 
        update_display();
}























char *intToBinStr(char *str, unsigned char n){
	if(n & 0x80) str[0] = '1'; else str[0] = '0';
	if(n & 0x40) str[1] = '1'; else str[1] = '0';
	if(n & 0x20) str[2] = '1'; else str[2] = '0';
	if(n & 0x10) str[3] = '1'; else str[3] = '0';
	if(n & 0x08) str[4] = '1'; else str[4] = '0';
	if(n & 0x04) str[5] = '1'; else str[5] = '0';
	if(n & 0x02) str[6] = '1';	else str[6] = '0';
	if(n & 0x01) str[7] = '1'; else str[7] = '0';
        
        str[8] = '\0';

	return str;
}

//---------------------------------------------------------------------------

//---------------------------------------------------------------------------


//---------------------------------------------------------------------------







//---------------------------------------------------------------------------

//---------------------------------------------------------------------------





void __fastcall Tfmain::control_listClickCheck(TObject *Sender)
{
        write_cycle();
}
//---------------------------------------------------------------------------

void __fastcall Tfmain::memo_infoKeyDown(TObject *Sender, WORD &Key,
      TShiftState Shift)
{
        write_cycle();         
}
//---------------------------------------------------------------------------

void __fastcall Tfmain::memo_infoKeyUp(TObject *Sender, WORD &Key,
      TShiftState Shift)
{
        write_cycle();         
}
//---------------------------------------------------------------------------


void __fastcall Tfmain::list_cycleClick(TObject *Sender)
{
        cycle_nbr = instr_nbr * CYCLES_PER_INSTR + StrToInt(list_cycle->ItemIndex);
        update_display();


}
//---------------------------------------------------------------------------











void __fastcall Tfmain::combo_typeSelect(TObject *Sender)
{
        switch(combo_type->ItemIndex){
                case 0:
                        control_list->Checked[0] = false;
                        control_list->Checked[1] = false;
                        break;

                case 1:
                        control_list->Checked[0] = true;
                        control_list->Checked[1] = false;
                        break;

                case 2:
                        control_list->Checked[0] = false;
                        control_list->Checked[1] = true;
                        break;

                case 3:
                        control_list->Checked[0] = true;
                        control_list->Checked[1] = true;
                        break;

        }
        write_cycle();
}
//---------------------------------------------------------------------------













    





//---------------------------------------------------------------------------

//---------------------------------------------------------------------------






















void __fastcall Tfmain::combo_aluAmuxSelect(TObject *Sender)
{
        int index = combo_aluAmux->ItemIndex;


        control_list->Checked[control_list->Items->IndexOf("alu_a_src_0")] = index & 0x01;
        control_list->Checked[control_list->Items->IndexOf("alu_a_src_1")] = index & 0x02;
        control_list->Checked[control_list->Items->IndexOf("alu_a_src_2")] = index & 0x04;
        control_list->Checked[control_list->Items->IndexOf("alu_a_src_3")] = index & 0x08;
        control_list->Checked[control_list->Items->IndexOf("alu_a_src_4")] = index & 0x10;
        control_list->Checked[control_list->Items->IndexOf("alu_a_src_5")] = index & 0x20;



        write_cycle();

}
//---------------------------------------------------------------------------




void __fastcall Tfmain::combo_aluBmuxSelect(TObject *Sender)
{
        int index = combo_aluBmux->ItemIndex;

        control_list->Checked[control_list->Items->IndexOf("alu_b_src_0")] = (index ) & 0x01;
        control_list->Checked[control_list->Items->IndexOf("alu_b_src_1")] = (index ) & 0x02;
        control_list->Checked[control_list->Items->IndexOf("alu_b_src_2")] = (index ) & 0x04;

        write_cycle();
}
//---------------------------------------------------------------------------
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

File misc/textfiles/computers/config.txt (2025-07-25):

Your CONFIG.SYS and AUTOEXEC.BAT by Barry Simon

                 Copyright (c) 1986, by Barry Simon
Written expressly for and posted on Compuserve's IBM Forum.  May only be 
reproduced commercially with the author's permission.  May only be 
distributed with this copyright notice intact.

Introduction

During the startup of an IBM or IBM compatible computer, the operating system 
looks for two files of user supplied commands which allow you to customize 
your system in various ways.  This article will attempt to explain some of 
the options available to you when you make these basic files.  While I have 
written it for the relative novice, I hope it may provide some useful new 
tricks even to the more experienced user.

These two files whose names must be CONFIG.SYS and AUTOEXEC.BAT should reside 
in the root directory of your boot diskette or of your hard disk if you have 
a bootable hard disk (i.e. if you can start your system from your hard disk 
without placing a diskette in drive A).  Actually, there is a method for 
placing the AUTOEXEC.BAT file in a subdirectory but despite the fact that 
I tend to be fanatical about keeping my root directory lean, I don't
recommend using this option.

When you turn on your computer, the CPU is setup to begin a program in the 
ROM (read only memory) that all IBM compatible machines have.  This ROM is 
distinct from and in addition to the working RAM (random access memory).  
When you are sold a machine with 256K of memory, that figure refers to the 
RAM.  There is an additional 16K-32K of ROM.  RAM is cleared whenever you 
turn off your machine or reboot while the ROM is permanently burned in and
should not change.

Booting Up

The program that is automatically run from ROM begins with a brief test 
(POST="power on self test") of various components of your computer.  If you 
have an XT or AT, the most noticeable part is the memory(RAM) test accompanied 
by counting up the memory on your screen as the test progresses.  This test 
is skipped when you do a warm reboot by hitting Ctrl-Alt-Del.  You may also 
notice your drives and printer "burping" as they get tested.

After this test, the machine searches for various "ROM extensions" that is 
additional ROM that can come with a hard disk or EGA card for example.  The 
program then searches first drive A and then a hard disk if you have a 
bootable hard disk for a diskette or disk program to transfer control to.  It 
transfers control to the very first sector on the disk which is called the 
boot sector.  When you format a diskette, a little program is placed in the 
boot sector which will display the message "non system disk, replace and hit 
any key".  When you transfer the operating system to the disk with the SYS 
command or via FORMAT/S, this boot sector program is changed to transfer 
control to a program which must be in the position immediately following the 
boot sector.

If the disk has the system on it, control is transferred successively to two 
hidden files which load the BIOS ("basic input/output system" part of which 
is in ROM) and the DOS ("Disk operating system").  When most users think of 
DOS they think of the familiar prompt and copy,.... commands.  These parts of 
the DOS are only loaded later; the part in the hidden file involves services 
provided by DOS to programmers rather than directly to users.  The two hidden 
files are called "IBMBIOS.COM" and "IBMDOS.COM" in PC-DOS and may have 
different names on other computers although surprisingly, the names persist 
even on some non-IBM brands!

Parenthetically, I want to note that there isn't really much hidden about 
hidden files.  As you may know, the DIRectory you are used to display gets 
its information from a special file also called the directory.  This file 
is essentially a little database with information about each file including 
the filename, extension, date and time of creation.  One byte in the record 
for each file is called the attribute byte and contains eight "switches" to 
keep track of things like whether the file is a volume label, read only, etc.  
One of these switches is whether the file is "hidden".  To anyone with any 
programming experience or with any of a large number of public domain or 
commercial programs, these files are not in any sense hidden.  The basic DOS
services like DIR and COPY are specially set up to ignore hidden files and 
that is the only sense in which these files are hidden.  The two system files 
are hidden because their location is critical for a successful boot-up and 
they are less likely to be moved by accident if they are hidden.
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

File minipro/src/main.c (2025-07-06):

/*
 * main.c - User interface and high-level operations.
 *
 * This file is a part of Minipro.
 *
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
 */

#define _GNU_SOURCE

#include <ctype.h>
#include <errno.h>
#include <libgen.h>
#include <signal.h>
#include <stdarg.h>
#include <stdio.h>
#include <stdlib.h>
#include <string.h>
#include <sys/stat.h>
#include <sys/time.h>
#include <getopt.h>
#include <unistd.h>

#include "database.h"
#include "jedec.h"
#include "ihex.h"
#include "srec.h"
#include "minipro.h"
#include "version.h"

#ifdef _WIN32
#include <shlwapi.h>
#include <fcntl.h>
#define STRCASESTR StrStrIA
#else
#define STRCASESTR strcasestr
#endif

#define VPP_VOLTAGE	 0
#define VCC_VOLTAGE	 1

#define READ_BUFFER_SIZE 65536
#define MIN(a, b)	 (((a) < (b)) ? (a) : (b))

static const char *user_id[] = {
	"user_id0", "user_id1", "user_id2", "user_id3",
	"user_id4", "user_id5", "user_id6", "user_id7"
};

static struct voltage_s {
	const char *name;
	uint8_t value;
} tl866a_vpp_voltages[] = { { "10", 0x40 }, { "12.5", 0x00 }, { "13.5", 0x30 },
			    { "14", 0x50 }, { "16", 0x10 },   { "17", 0x70 },
			    { "18", 0x60 }, { "21", 0x20 },   { NULL, 0x00 } },
  tl866a_vcc_voltages[] = { { "3.3", 0x02 }, { "4", 0x01 },   { "4.5", 0x05 },
			    { "5", 0x00 },   { "5.5", 0x04 }, { "6.5", 0x03 },
			    { NULL, 0x00 } },
  tl866ii_vpp_voltages[] = { { "9", 0x10 },    { "9.5", 0x20 },
			     { "10", 0x30 },   { "11", 0x40 },
			     { "11.5", 0x50 }, { "12", 0x00 },
			     { "12.5", 0x60 }, { "13", 0x70 },
			     { "13.5", 0x80 }, { "14", 0x90 },
			     { "14.5", 0xa0 }, { "15.5", 0xb0 },
			     { "16", 0xc0 },   { "16.5", 0xd0 },
			     { "17", 0xe0 },   { "18", 0xf0 },
			     { NULL, 0x00 } },
  tl866ii_vcc_voltages[] = { { "3.3", 0x01 }, { "4", 0x02 },   { "4.5", 0x03 },
			     { "5", 0x00 },   { "5.5", 0x04 }, { "6.5", 0x05 },
			     { NULL, 0x00 } },
  t48_vcc_voltages[] = { { "1.75", 0x01 },
                         { "1.8",  0x02 },
                         { "1.9",  0x03 },
                         { "2",  0x04 },
                         { "2.1",  0x05 },
                         { "2.2",  0x06 },
                         { "2.3",  0x08 },
                         { "2.4",  0x09 },
                         { "2.5",  0x0a },
                         { "2.6",  0x0b },
                         { "2.7",  0x0d },
                         { "2.8",  0x0e },
                         { "2.9",  0x0f },
                         { "3",  0x10 },
                         { "3.3",  0x14 },
                         { "3.5",  0x16 },
                         { "3.7",  0x18 },
                         { "3.8",  0x1a },
                         { "4",  0x1c },
                         { "4.2",  0x1e },
                         { "4.3",  0x20 },
                         { "4.4",  0x21 },
                         { "4.5",  0x22 },
                         { "4.7",  0x25 },
                         { "4.8",  0x26 },
                         { "4.9",  0x27 },
                         { "5",  0x28 },
                         { "5.2",  0x2b },
                         { "5.3",  0x2c },
                         { "5.4",  0x2d },
                         { "5.5",  0x2f },
                         { "5.6",  0x30 },
                         { "5.7",  0x31 },
                         { "5.8",  0x32 },
                         { "5.9",  0x33 },
                         { "6",  0x34 },
                         { "6.1",  0x35 },
                         { "6.2",  0x36 },
                         { "6.3",  0x38 },
                         { "6.5",  0x3b },
                         { "6.6",  0x3c },
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
                         { NULL, 0x00 } },
  t48_vpp_voltages[] = { { "9", 0x00 },
                         { "9.5", 0x01 },
                         { "10", 0x03 },
                         { "11", 0x07 },
                         { "11.5", 0x09 },
                         { "12", 0x0b },
                         { "12.5", 0x0d },
                         { "13", 0x0e },
                         { "13.5", 0x11 },
                         { "14", 0x13 },
                         { "14.5", 0x15 },
                         { "15.5", 0x18 },
                         { "16", 0x1a },
                         { "16.5", 0x1c },
                         { "17", 0x1e },
                         { "18", 0x23 },
                         { "21", 0x2f },
                         { "25", 0x3e },
                         { NULL, 0x00 } },
  logic_voltages[] = { { "3.5", 0x04 },
		       { "3.3", 0x03 },
		       { "3", 0x02 },
		       { "2.5", 0x01 },
		       { "2.35", 0x00 },
		       { NULL, 0x00 } };

static struct option long_options[] = {
	{ "pulse", required_argument, NULL, 2 },
	{ "vpp", required_argument, NULL, 2 },
	{ "vdd", required_argument, NULL, 2 },
	{ "vcc", required_argument, NULL, 2 },
	{ "fuses", no_argument, NULL, 1 },
	{ "uid", no_argument, NULL, 1 },
	{ "lock", no_argument, NULL, 1 },
	{ "infoic", required_argument, NULL, 3 },
	{ "logicic", required_argument, NULL, 4 },
	{ "logicic_out", required_argument, NULL, 5 },
	{ "algorithms", required_argument, NULL, 6 },
	{ "list", no_argument, NULL, 'l' },
	{ "search", required_argument, NULL, 'L' },
	{ "get_info", required_argument, NULL, 'd' },
	{ "device", required_argument, NULL, 'p' },
	{ "programmer", required_argument, NULL, 'q' },
	{ "presence_check", no_argument, NULL, 'k' },
	{ "query_supported", no_argument, NULL, 'Q' },
	{ "auto_detect", required_argument, NULL, 'a' },
	{ "write", required_argument, NULL, 'w' },
	{ "read", required_argument, NULL, 'r' },
	{ "verify", required_argument, NULL, 'm' },
	{ "blank_check", no_argument, NULL, 'b' },
	{ "erase", no_argument, NULL, 'E' },
	{ "read_id", no_argument, NULL, 'D' },
	{ "page", required_argument, NULL, 'c' },
	{ "skip_erase", no_argument, NULL, 'e' },
	{ "skip_verify", no_argument, NULL, 'v' },
	{ "skip_id", no_argument, NULL, 'x' },
	{ "no_size_error", no_argument, NULL, 's' },
	{ "no_size_warning", no_argument, NULL, 'S' },
	{ "no_id_error", no_argument, NULL, 'y' },
	{ "format", required_argument, NULL, 'f' },
	{ "version", no_argument, NULL, 'V' },
	{ "pin_check", no_argument, NULL, 'z' },
	{ "logic_test", no_argument, NULL, 'T' },
	{ "icsp_vcc", no_argument, NULL, 'i' },
	{ "icsp_no_vcc", no_argument, NULL, 'I' },
	{ "protect", no_argument, NULL, 'P' },
	{ "unprotect", no_argument, NULL, 'u' },
	{ "hardware_check", no_argument, NULL, 't' },
	{ "update", required_argument, NULL, 'F' },
	{ "help", no_argument, NULL, 'h' },
	{ NULL, 0, NULL, 0 }
};

static char signon[] = "minipro version %s     A free and open TL866 series programmer\n";
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

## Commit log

2025-06-14 moving floppy drive documents to general_docs/
    [Z80-FDC-V2-B_Cu.gbr, Z80-FDC-V2-B_Mask.gbr, Z80-FDC-V2-B_Silkscreen.gbr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]
2025-06-18 floppy drive kernel code
    [main.kicad_sch]
2025-06-18 fixes to floppy driver
    [kernel.asm]
2025-06-19 floppy disk driver fixes
    [kernel.asm]
2025-06-19 floppy disk driver
2025-06-22 major changes to floppy drive driver
2025-06-22 changes to ucode progammer
    [main.obj, photon.obj]
2025-06-25 various fixed for floppy disk driver - working now
    [main.kicad_sch]
2025-06-26 decreased delay in floppy driver calls. first byte write takes 64us so not much need to wait for 64us
2025-06-27 floppy driver updates
2025-06-28 updates to floppy driver
2025-06-29 updates to main kernel - adding floppy disk driver
2025-07-01 fixing floppy driver code
    [kernel.asm]
2025-07-01 adding option for 512-byte sectors
    [kernel_simple.obj]
2025-07-02 fixing floppy driver 512 byte format
    [kernel.asm]
2025-07-04 add falstad circuit sim
    [amp-diff.txt, diff.txt]
2025-07-18 all backdated commits
    [main.kicad_sch]
2025-07-22 reverting uart changes
2025-07-22 adding 2nd uart
2025-07-24 second uart working ok and new kernel updated
2025-07-25 unzip textfiles
    [config.txt, keylock.sch, law.sch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]
2025-10-11 adding hierarchical sheets to schematic
2025-10-12 schem cleanup
    [front_panel.kicad_sch, main.csv, main.kicad_pcb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]
2025-10-13 fixing printf mistakes
2025-10-16 splitting schematic into blocks
    [front_panel.kicad_sch, main.kicad_sch, memory_peripherals.kicad_sch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]
2025-10-18 adding back old schematics
    [100SP1T1B4M2QE.step, ST141D00.step, TIL311--3DModel-STEP-56544.STEP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]
2025-10-23 fixing declaration of types and variables inside libraries
    [main.kicad_sch, main.obj, photon.obj]
2025-10-25 switched license to gpl2
2025-11-16 the issue with printf was caused by get_type. it was checking prematurely for pointers. that should not happen because check for pointers is done by declare_local/global etc

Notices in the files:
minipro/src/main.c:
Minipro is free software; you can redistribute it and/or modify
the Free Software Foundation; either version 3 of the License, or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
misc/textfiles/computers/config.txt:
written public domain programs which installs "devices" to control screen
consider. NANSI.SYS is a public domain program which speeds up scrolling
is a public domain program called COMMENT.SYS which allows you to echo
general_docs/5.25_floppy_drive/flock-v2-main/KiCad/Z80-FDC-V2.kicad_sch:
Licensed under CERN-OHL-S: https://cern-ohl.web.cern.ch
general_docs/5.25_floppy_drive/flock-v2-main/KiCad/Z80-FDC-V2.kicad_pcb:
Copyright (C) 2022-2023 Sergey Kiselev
